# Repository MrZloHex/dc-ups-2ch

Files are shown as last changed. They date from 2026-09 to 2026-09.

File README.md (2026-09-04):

# DC-UPS-2CH — ESP32 backup power controller for network gear

> Two-channel DC UPS for a Wi-Fi router + ONT / optical terminal, built around
> an off-the-shelf 24 V AC/DC brick, an XL4016 charger, an AGM battery and two
> XL6009 buck-boost outputs. An ESP32 supervises the whole thing, exposes a
> local web panel, sends notifications through `ntfy.sh`, and even answers
> read-only status commands back through the same ntfy topic.

**Firmware version:** `2026.09.02-v6` · **Hardware:** `v2.1` · **License:** [GPL-3.0-or-later](LICENSE)
· **[Documentation site](https://mrzlohex.github.io/dc-ups-2ch/)**
· Passport [RU](docs/DC_UPS_documentation_v6.tex) / [EN](docs/DC_UPS_documentation_v6_en.tex)
· User manual [RU](docs/DC_UPS_user_manual_v6.tex) / [EN](docs/DC_UPS_user_manual_v6_en.tex)

<p align="center">
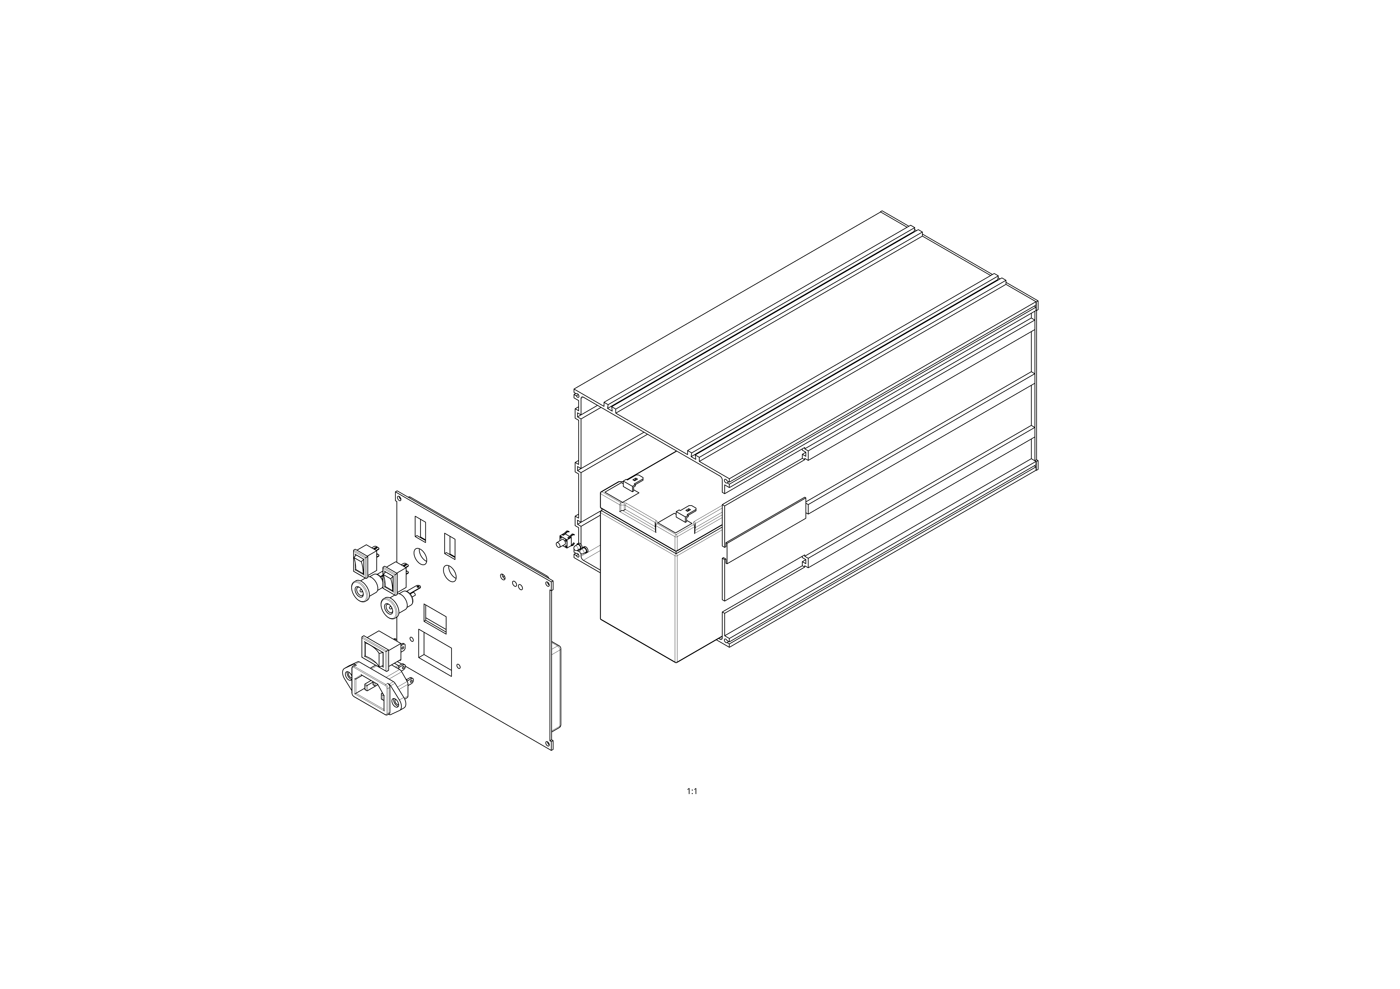
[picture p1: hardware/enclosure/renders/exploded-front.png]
Exploded isometric — front panel, battery, aluminium extrusion shell
  
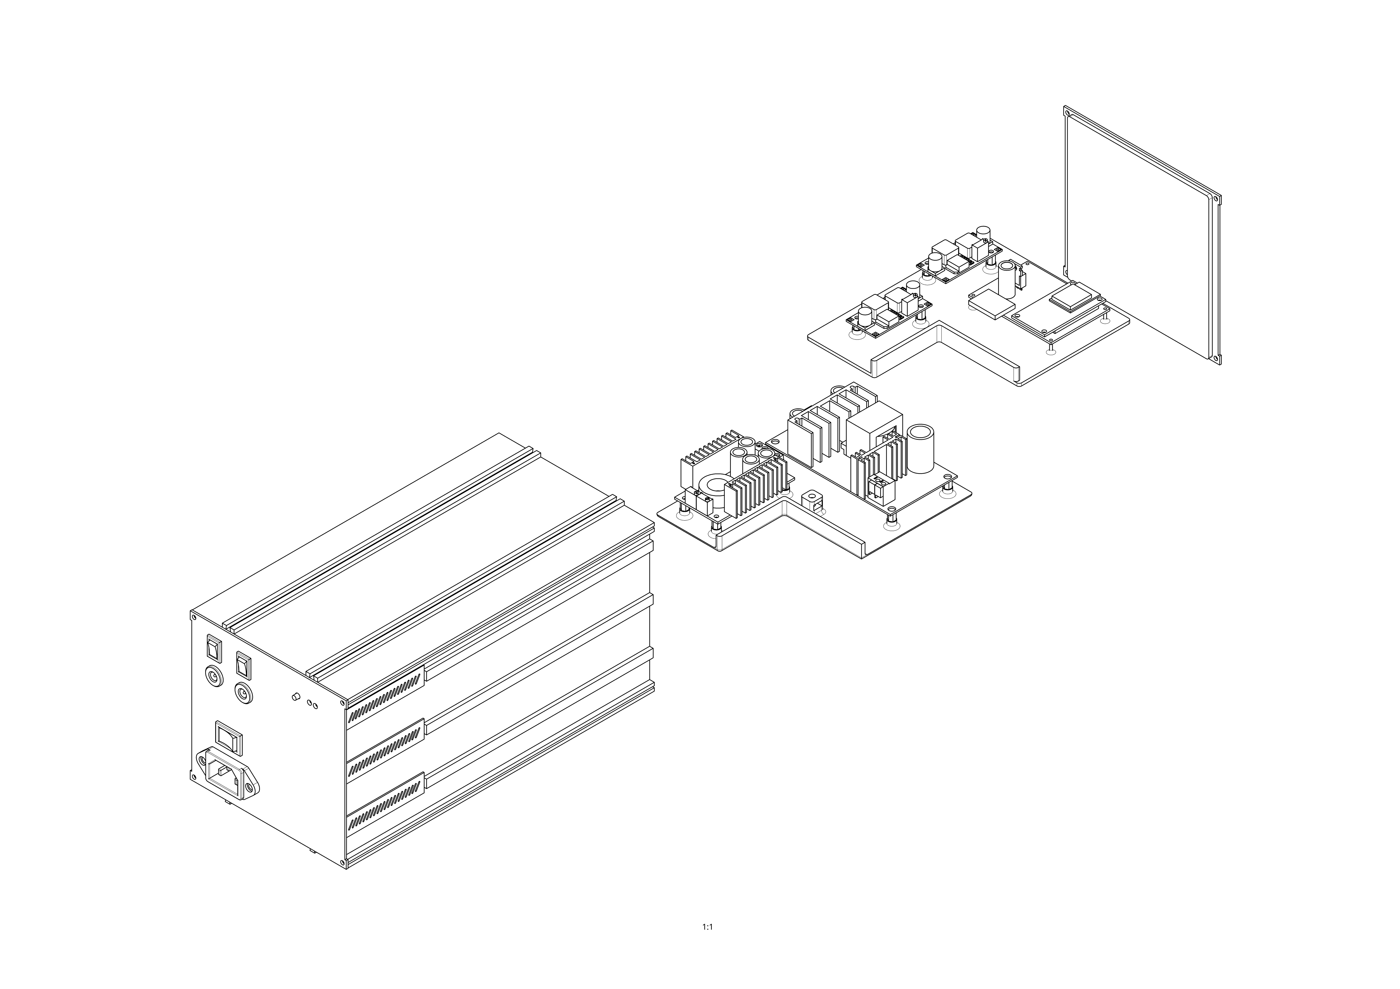
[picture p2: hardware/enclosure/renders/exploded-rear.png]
Exploded isometric — rear panel with two-tier PCB stack (XL4016 charger + 2× XL6009 boosters + ESP32)
  
</p>

<p align="center"><sub>
  Exploded isometric views from the public
  <a href="https://cad.onshape.com/documents/ea66c330322b844216a03713/w/1c92cc427e11be4cf82566dd/e/3ae3fbe0cc714edd3fc95852">Onshape</a>
  model. Left: front panel with IEC C14 inlet and two DC output sockets pulled off, AGM battery visible in the aluminium extrusion. Right: back panel and the two-tier power PCB assembly pulled off.
  STEP files: <a href="hardware/enclosure/step/">hardware/enclosure/step/</a>.
</sub></p>

---

## Why this exists

This project keeps the hardware boring (all modules you can buy on any
marketplace) and puts the intelligence in the ESP32 firmware:

- automatic mains ↔ battery switching (via the shared 13.8 V bus, no relay);
- true low-voltage disconnect with configurable thresholds and hysteresis;
- **two independent DC outputs** (ROUTER, ONT) with per-channel manual override
  and remote restart;
- automatic Wi-Fi / internet health check with staged recovery (probe →
  restart the failing layer: ONT if only WAN is dead, ROUTER if Wi-Fi itself
  is gone → restart both → optionally reboot the ESP);
- push notifications via [ntfy.sh](https://ntfy.sh/) — outages, LVD, boots,
  auto-recovery actions;
- inbound read-only commands over ntfy: `!ups`, `!ups status`, `!ups ping`;
- self-hosted web panel with mDNS (`http://dc-ups.local/`);
- captive-portal setup AP (`DC-UPS-Setup`) when Wi-Fi isn't configured or dies;
- two deep-sleep modes: emergency (timer wake, keeps checking mains) and
  shelf-sleep (button wake only, for storage/transport).

## Hardware overview

```
230 V AC ─▶ AC/DC 24 V ─▶ XL4016 CC/CV ─▶ 13.8 V bus ◀─▶ AGM 12 V 7 Ah
                                              │
                          ┌───────────────────┼───────────────────┐
                          ▼                                       ▼
                  P-MOSFET + XL6009                       P-MOSFET + XL6009
                          │                                       │
                          ▼                                       ▼
                        ROUTER                                  ONT / AUX
                          ▲                                       ▲
                          │                                       │
                          └─── GPIO32 ─── ESP32 ─── GPIO25 ───────┘
                                            │
                                            ▼
                                    ADC ◀── 24 V bus & battery
                                            │
                                    Button ─┘ (GPIO14, EXT0 wake)
```

Full wiring, GPIO map, calibration and BOM: [`hardware/README.md`](hardware/README.md).

## Getting started

### Prerequisites

- ESP32 DevKit v1 (ESP-WROOM-32, USB-C or micro, CH340/CP2102 — either is fine)
- [PlatformIO Core](https://platformio.org/install/cli) (or the VS Code extension)
- The rest of the hardware from [`hardware/README.md`](hardware/README.md)

### Build & flash

```bash
git clone https://github.com/MrZloHex/dc-ups-2ch.git
cd dc-ups-2ch

# Everything at once (firmware + PDFs), stamped with version + git hash + date:
make                   # or: make all
make upload            # firmware + flash
make monitor           # 115200 baud

# Or use PlatformIO directly — the pre-script still stamps the build:
pio run
pio run -t upload
pio device monitor
```

The version stamped into the firmware and both PDFs comes from the top-level
`VERSION` file plus `git rev-parse --short HEAD` and today's UTC date. It
shows up in the serial boot log, in the web panel header, in ntfy status
replies, and on the printable device label. Override any of them:

```bash
make VERSION=2026.10.01-v7            # bump semantic version for a release build
make DOCREV="Rev. 3"                  # override the document revision label
```

`make version` prints exactly what will be stamped, `make help` lists every
target.

### First boot

1. On first boot (or if the saved Wi-Fi credentials fail) the device spins up
   an open access point named **`DC-UPS-Setup`** with password
   `dc-ups-setup`.
2. Connect any phone/laptop, browse to `http://192.168.4.1/`, fill in your
   Wi-Fi SSID/password, your `ntfy.sh` topic (**pick a long, unguessable
   string** — the topic is effectively a secret URL), and hit save. The device
   reboots.
3. From now on the panel lives at `http://dc-ups.local/` (mDNS) or the IP the
   ESP32 pushes to your ntfy topic on every successful connect.

### Button reference

| Gesture | Action |
|---|---|
| 1× short press | send full status message to ntfy (2× green blink = ok) |
| 2× short press | open setup AP for 15 minutes (both LEDs blink once) |
| Hold 10 s | Shelf Sleep — everything off, wake only by another press |
| Any press in shelf | boot the device again |

### ntfy commands

Send any of these to your topic (e.g. from the ntfy app or `curl`):

```
!ups          # or "!ups status" — reply with full status
!ups ping     # reply "PONG ..." + full status
```

The device polls the topic ~every 15 s while online. There are **no
inbound control commands** on purpose: the topic is only a read-only status
channel.

## Documentation

- **[Documentation site](https://mrzlohex.github.io/dc-ups-2ch/)** - GitHub
  Pages landing page linking to every PDF. This URL is also encoded in the QR
  code printed on the enclosure label - scan the label with any phone to jump
  straight here.
- [`hardware/README.md`](hardware/README.md) - BOM, GPIO map, ASCII wiring, calibration
- [`hardware/enclosure/`](hardware/enclosure/) - 3D-printable case
- [`docs/DC_UPS_documentation_v6.tex`](docs/DC_UPS_documentation_v6.tex) /
  [`docs/DC_UPS_documentation_v6_en.tex`](docs/DC_UPS_documentation_v6_en.tex)
  - full passport, service manual, warranty template (Russian and English
  variants; both stamped from the same `build_info.tex`)
- [`docs/DC_UPS_user_manual_v6.tex`](docs/DC_UPS_user_manual_v6.tex) /
  [`docs/DC_UPS_user_manual_v6_en.tex`](docs/DC_UPS_user_manual_v6_en.tex)
  - short A5 user manual (Russian and English) with local-panel + docs-site QR codes
- [`docs/DC_UPS_label_v6.tex`](docs/DC_UPS_label_v6.tex) - 90 × 55 mm enclosure
  label; QR code encodes the documentation-site URL above
- [Printables](https://www.printables.com/model/1832207-dc-ups-2ch-esp32-dc-ups-for-router-ont) - Page on printables
- [MakerWorld](https://makerworld.com/en/models/3258940-dc-ups-2ch-esp32-dc-ups-for-router-ont#profileId-3694235) - Page on MakerWorld

## Contributing

Issues and PRs welcome. Please:

- keep the firmware buildable with the pinned `espressif32@^6.9.0` platform
  (the watchdog and RTC-GPIO APIs used here are frozen on that major);
- avoid new external Arduino libraries — everything so far fits in the core;
- match the module split described above rather than dumping new features
  into `main.cpp`.

## License

**Firmware & documentation:** GNU General Public License v3.0 or later —
see [LICENSE](LICENSE). If you build a product on top of this firmware,
you must make your source available under the same license.

Hardware wiring is documented for personal / educational use; recycled
AC/DC bricks and Chinese DC/DC modules used in the BOM come with their
own certifications (or don't).

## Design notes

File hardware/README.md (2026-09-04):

# DC-UPS-2CH — hardware notes

> This is a "buy the modules, don't design a PCB" project. Everything is
> wired point-to-point (or on a small perfboard) so anyone with a soldering
> iron can reproduce it. 

## Bill of materials

| # | Part | Notes |
|---|---|---|
| 1 | ESP32 DevKit v1 (ESP-WROOM-32) | USB-C or micro; CH340/CP2102 both fine |
| 2 | AC/DC brick 230 V → 24 V, ≥ 60 W | any reputable enclosed switcher |
| 3 | XL4016 CC/CV step-down module | set to **13.8 V** open-circuit, current-limit ≈ **1.5 A** |
| 4 | AGM/SLA battery 12 V, 7 Ah | any brand that fits your enclosure; keep the terminal type same  |
| 5 | 2 × XL6009 buck-boost | one per output; adjust to the actual load voltage before wiring  |
| 6 | 2 × P-MOSFET, e.g. IRF9Z34N | high-side switch; needs to handle your peak output current |
| 7 | 2 × 2N2222 NPN | gate driver from a 3.3 V GPIO to a P-MOSFET gate |
| 8 | 2 × 10 kΩ gate pull-up (Gate ↔ Source) | keeps the P-MOSFET fully off when the NPN is off |
| 9 | 2 × 100 kΩ + 2 × 10 kΩ | voltage dividers for `V_BATT` and `V_24V` sensing |
|10 | 1 × 5 A automotive fuse + holder | mount at the battery `+` terminal, as close as possible |
|11 | Reverse-blocking / OR-ing diode (optional) | if your specific arrangement needs it — depends on charger topo  |
|12 | 1 × 6 × 6 mm tact switch | GPIO14 to GND (uses internal pull-up) |
|13 | 2 × LED (green + red) + series resistors | ~330 Ω is fine for 3.3 V drive |
|14 | Screw terminals / DC barrel jacks | pick to match your router's / ONT's input plugs |

Anything not on this list (heatsinks, standoffs, wire, enclosure) is up to you.

## GPIO map

| Pin | Direction | Function |
|---|---|---|
| `GPIO35` | ADC1_IN7  | `V_BATT` sense (100 kΩ / 10 kΩ divider → x11) |
| `GPIO34` | ADC1_IN6  | `V_24V` sense (100 kΩ / 10 kΩ divider → x11) |
| `GPIO32` | OUT | `ROUTER` channel: NPN base → P-MOSFET gate |
| `GPIO25` | OUT | `ONT` channel: NPN base → P-MOSFET gate |
| `GPIO14` | IN_PULLUP | service button to GND; **RTC-GPIO → EXT0 wake source**|
| `GPIO13` | OUT | green LED: mains present |
| `GPIO12` | OUT | red LED: battery / warning / fault |

> **ADC1 only.** Voltage sensing must stay on GPIO32-39. ADC2 is unusable
> while Wi-Fi is on.

> **GPIO14 is a specific choice.** It's an RTC-GPIO on the classic ESP32,
> which is exactly what's needed to wake from Shelf Sleep via EXT0. Do not
> reassign to a non-RTC pin.

## Voltage divider math

```
V_pin = V_source · R_bottom / (R_top + R_bottom)
V_pin = V_source · 10k / (100k + 10k) = V_source / 11

At V_source = 15.0 V  ->  V_pin ≈ 1.36 V  (well inside 0..3.3 V ADC range)
At V_source = 13.8 V  ->  V_pin ≈ 1.25 V
At V_source = 24.0 V  ->  V_pin ≈ 2.18 V
```

The firmware assumes `DIV = 11.0` for both channels. If you use different
resistors, edit `DIV_VBATT` / `DIV_VGRID` in
[`include/ups_common.h`](../include/ups_common.h). Fine per-device correction
(±3 %) is done at runtime through the web panel using a multimeter — no code
change needed.

## ASCII wiring (one channel — mirror for the second)

```
              +Vbus 13.8 V (charger + battery via fuse)
                          │                  │
                          │                  │ 
                          │Source           100 KOhm  
                     ┌────┴─────┐    Gate    │ 	
                     │ P-MOSFET │ ◀──────────┤
                     │ (S=Vbus) │            │
                     └────┬─────┘            │
                          │                100 Ohm  
                     Drain│                  │
                          ▼                  │
                    XL6009 IN                │
                                             │Collector
                                             │
                                   ┌─────────┴──┐
                                   │   2N2222   │  (BJT open when GPIO HIGH)
           GPIO32 ── 1kOhm ──┬───▶ │            │
        (or  GPIO25)      10 KOhm  └────────────┘
                             │
                            GND
```

## Charger settings (XL4016)

1. Disconnect everything downstream.
2. Feed the XL4016 from the 24 V brick.
3. **Voltage pot:** turn the CV trim until the open-circuit output at the
   pads that will feed the battery reads exactly **13.8 V** at the battery
   terminals. Compensate for wire drop by measuring at the battery, not at
   the module.
4. **Current pot:** short the output through an ammeter for a brief pulse
   (or use a resistive dummy load) and set the CC limit to **≈ 1.5 A**.
5. Only then connect the battery.

## Setting the XL6009 outputs

1. Look up the required voltage of the load (router: usually 12 V, ONT:
   often 12 V, sometimes 9 V). Verify with a multimeter on the *original*
   PSU under no load.
2. Feed each XL6009 from the 13.8 V bus (through a temporary lead — do
   **not** connect the load yet).
3. Turn the output pot until the measured voltage matches the target
   within ±0.2 V.
4. Only then connect the load through the DC barrel jack.

## Calibration

The web panel has two calibration fields (`Cal battery` / `Cal 24 V`).
Procedure:

1. Measure the real battery voltage with a multimeter directly at the
   battery terminals.
2. Type the exact reading into the *battery* calibration field and press
   the corresponding button. The firmware computes a per-device
   correction factor and saves it in NVS.
3. Repeat for the 24 V line, measured directly at the AC/DC brick output.

The correction factors are stored as `calVbatt` / `calVgrid` floats
(default 1.000) in NVS and are picked up on the next reading.

## Safety 

- **230 V AC is present inside the enclosure.** Before opening: unplug
  mains, disconnect the battery fuse.
- The AGM battery is a *short-circuit hazard* — hundreds of amps into a
  screwdriver dropped across the terminals. Always disconnect the fuse
  first when working near it.
- Never bypass the fuse. Its job is to isolate a dead-short before the
  battery cables catch fire.
- Do not skip the initial no-load setup of the XL6009 outputs — a wrong
  voltage will kill a router.
- The AGM battery is a consumable. Replace when the measured autonomy
  drops noticeably, the case bulges, or the terminals show corrosion.

## Suggested layout

Keep the AC/DC brick, the XL4016 and the battery physically separated
from the ESP32 and the two XL6009 outputs, or at least route wiring so
that the switching noise from the buck-boost modules doesn't couple into
the ADC dividers. A short common ground point (star ground) near the
battery negative helps a lot.

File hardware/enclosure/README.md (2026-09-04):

# DC-UPS-2CH — enclosure

3D-printable enclosure for the DC-UPS-2CH controller. Modelled in
[Onshape](https://cad.onshape.com/documents/ea66c330322b844216a03713/w/1c92cc427e11be4cf82566dd/e/3ae3fbe0cc714edd3fc95852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)

<p align="center">
  Exploded isometric — front panel, battery, aluminium extrusion shell
  Exploded isometric — rear panel with PCB stack
</p>

## Contents

```
hardware/enclosure/
├── README.md              this file
├── renders/
│   ├── exploded-front.png     iso view: front panel + battery exploded
│   └── exploded-rear.png      iso view: back panel + PCB stack exploded
├── step/                  neutral STEP exports (for CAD / re-modelling)
│   ├── Main.step              main aluminium-extrusion body
│   ├── Level 1.step           lower PCB tier (charger + XL6009 outputs)
│   ├── Level 2.step           upper PCB tier (ESP32 + I/O)
│   ├── Side 1.step            front panel (IEC C14 inlet + DC output sockets)
│   ├── Side 2.step            rear panel (button + LEDs + cable exits)
│   ├── Battery Holder.step    AGM 12 V / 7 Ah cradle
│   └── Dummy Sky.step         placeholder for the top cover volume
└── 3mf/                   slicer-ready assemblies (drop straight into a slicer)
    ├── DC_UPS.3mf             full assembly view
    ├── Main.3mf, Level 1.3mf, Level 2.3mf, Side 1.3mf, Side 2.3mf,
    └── Battery Holder.3mf, Dummy Sky.3mf
```

## Print settings (baseline)

| Setting | Value |
|---|---|
| Material | PETG (preferred) or ABS/ASA — this thing sits next to a  |
| | charger that gets warm. **Not PLA** for the case body. |
| Nozzle | 0.4 mm |
| Layer height | 0.20 mm |
| Walls | 4 perimeters (strength around threaded inserts) |
| Top/bottom | 5 layers each |
| Infill | 25–30 % gyroid |
| Supports | Only for lid cutouts if needed — orient case bottom |
| | opening-up so the battery bay prints support-free |
| Brim | 5 mm on the case bottom, none on the lid |

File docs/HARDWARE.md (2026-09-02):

# DC-UPS-2CH — hardware notes

> This is a "buy the modules, don't design a PCB" project. Everything is
> wired point-to-point (or on a small perfboard) so anyone with a soldering
> iron can reproduce it. The full Russian passport (`DC_UPS_documentation_v6.tex`)
> has the same information plus service checklists, warranty template and
> service diagrams — this file is the English quick reference.

## Bill of materials

| # | Part | Notes |
|---|---|---|
| 1 | ESP32 DevKit v1 (ESP-WROOM-32) | USB-C or micro; CH340/CP2102 both fine |
| 2 | AC/DC brick 230 V → 24 V, ≥ 60 W | any reputable enclosed switcher |
| 3 | XL4016 CC/CV step-down module | set to **13.8 V** open-circuit, current-limit ≈ **1.5 A** |
| 4 | AGM/SLA battery 12 V, 7 Ah | any brand that fits your enclosure; keep the terminal type same  |
| 5 | 2 × XL6009 buck-boost | one per output; adjust to the actual load voltage before wiring  |
| 6 | 2 × P-MOSFET, e.g. IRF9Z34N | high-side switch; needs to handle your peak output current |
| 7 | 2 × 2N2222 NPN | gate driver from a 3.3 V GPIO to a P-MOSFET gate |
| 8 | 2 × 10 kΩ gate pull-up (Gate ↔ Source) | keeps the P-MOSFET fully off when the NPN is off |
| 9 | 2 × 100 kΩ + 2 × 10 kΩ | voltage dividers for `V_BATT` and `V_24V` sensing |
|10 | 1 × 5 A automotive fuse + holder | mount at the battery `+` terminal, as close as possible |
|11 | Reverse-blocking / OR-ing diode (optional) | if your specific arrangement needs it — depends on charger topo  |
|12 | 1 × 6 × 6 mm tact switch | GPIO14 to GND (uses internal pull-up) |
|13 | 2 × LED (green + red) + series resistors | ~330 Ω is fine for 3.3 V drive |
|14 | Screw terminals / DC barrel jacks | pick to match your router's / ONT's input plugs |

Anything not on this list (heatsinks, standoffs, wire, enclosure) is up to you.

## GPIO map

| Pin | Direction | Function |
|---|---|---|
| `GPIO35` | ADC1_IN7  | `V_BATT` sense (100 kΩ / 10 kΩ divider → x11) |
| `GPIO34` | ADC1_IN6  | `V_24V` sense (100 kΩ / 10 kΩ divider → x11) |
| `GPIO32` | OUT | `ROUTER` channel: NPN base → P-MOSFET gate |
| `GPIO25` | OUT | `ONT` channel: NPN base → P-MOSFET gate |
| `GPIO14` | IN_PULLUP | service button to GND; **RTC-GPIO → EXT0 wake source**|
| `GPIO13` | OUT | green LED: mains present |
| `GPIO12` | OUT | red LED: battery / warning / fault |

> **ADC1 only.** Voltage sensing must stay on GPIO32-39. ADC2 is unusable
> while Wi-Fi is on.

> **GPIO14 is a specific choice.** It's an RTC-GPIO on the classic ESP32,
> which is exactly what's needed to wake from Shelf Sleep via EXT0. Do not
> reassign to a non-RTC pin.

## Voltage divider math

```
V_pin = V_source · R_bottom / (R_top + R_bottom)
V_pin = V_source · 10k / (100k + 10k) = V_source / 11

At V_source = 15.0 V  ->  V_pin ≈ 1.36 V  (well inside 0..3.3 V ADC range)
At V_source = 13.8 V  ->  V_pin ≈ 1.25 V
At V_source = 24.0 V  ->  V_pin ≈ 2.18 V
```

The firmware assumes `DIV = 11.0` for both channels. If you use different
resistors, edit `DIV_VBATT` / `DIV_VGRID` in
[`include/ups_common.h`](../include/ups_common.h). Fine per-device correction
(±3 %) is done at runtime through the web panel using a multimeter — no code
change needed.

## ASCII wiring (one channel — mirror for the second)

```
              +Vbus 13.8 V (charger + battery via fuse)
                          │
                          │
                     ┌────┴─────┐    Gate 10 kΩ pull-up
                     │  P-MOSFET │ ◀──────────┐
                     │  (S=Vbus) │            │
                     └────┬─────┘             │
                          │                   │
                     Drain│                   │
                          ▼                   │
                    XL6009 IN                 │
                          │                   │
                    XL6009 OUT ─▶ ROUTER / ONT│
                                              │
                                              │
                                   ┌──────────┴──┐
                                   │   2N2222     │  (BJT open when GPIO HIGH)
                                   │  base ← 1kΩ │
                                   │              │
                          GPIO32 ─▶│ base         │
                    (or  GPIO25)   │ collector ──►│ P-MOSFET Gate
                                   │ emitter ─── GND
                                   └──────────────┘
```

Logic:

- GPIO **HIGH** → NPN saturates → pulls the P-MOSFET gate to GND
  → **P-MOSFET conducts → load ON**.
- GPIO **LOW** → NPN off → gate is held at Vbus by the 10 kΩ pull-up
  → **P-MOSFET off → load OFF**.

## Charger settings (XL4016)

1. Disconnect everything downstream.
2. Feed the XL4016 from the 24 V brick.
3. **Voltage pot:** turn the CV trim until the open-circuit output at the
   pads that will feed the battery reads exactly **13.8 V** at the battery
   terminals. Compensate for wire drop by measuring at the battery, not at
   the module.
4. **Current pot:** short the output through an ammeter for a brief pulse
   (or use a resistive dummy load) and set the CC limit to **≈ 1.5 A**.
5. Only then connect the battery.

## Setting the XL6009 outputs

1. Look up the required voltage of the load (router: usually 12 V, ONT:
   often 12 V, sometimes 9 V). Verify with a multimeter on the *original*
   PSU under no load.
2. Feed each XL6009 from the 13.8 V bus (through a temporary lead — do
   **not** connect the load yet).
3. Turn the output pot until the measured voltage matches the target
   within ±0.2 V.
4. Only then connect the load through the DC barrel jack.

## Calibration

The web panel has two calibration fields (`Cal battery` / `Cal 24 V`).
Procedure:

1. Measure the real battery voltage with a multimeter directly at the
   battery terminals.
2. Type the exact reading into the *battery* calibration field and press
   the corresponding button. The firmware computes a per-device
   correction factor and saves it in NVS.
3. Repeat for the 24 V line, measured directly at the AC/DC brick output.

The correction factors are stored as `calVbatt` / `calVgrid` floats
(default 1.000) in NVS and are picked up on the next reading.

## Safety 

- **230 V AC is present inside the enclosure.** Before opening: unplug
  mains, disconnect the battery fuse.
- The AGM battery is a *short-circuit hazard* — hundreds of amps into a
  screwdriver dropped across the terminals. Always disconnect the fuse
  first when working near it.
- Never bypass the fuse. Its job is to isolate a dead-short before the
  battery cables catch fire.
- Do not skip the initial no-load setup of the XL6009 outputs — a wrong
  voltage will kill a router.
- The AGM battery is a consumable. Replace when the measured autonomy
  drops noticeably, the case bulges, or the terminals show corrosion.

## Suggested layout

Keep the AC/DC brick, the XL4016 and the battery physically separated
from the ESP32 and the two XL6009 outputs, or at least route wiring so
that the switching noise from the buck-boost modules doesn't couple into
the ADC dividers. A short common ground point (star ground) near the
battery negative helps a lot.

## Enclosure

A 3D-printable enclosure lives at
[`../hardware/enclosure/`](../hardware/enclosure/). Modelled in
Onshape, distributed as STEP files (import directly in PrusaSlicer /
Bambu Studio / OrcaSlicer), licensed under CC-BY-SA 4.0. Ready-to-paste
listings for Printables and MakerWorld are in the same folder.

Recommended print: **PETG** (or ABS/ASA) — not PLA, because the
charger and both DC/DC modules run warm enough to creep PLA over time.
0.20 mm layers, 4 perimeters, 25–30 % gyroid infill, supports only for
lid cutouts.

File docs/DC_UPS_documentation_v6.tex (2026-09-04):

\documentclass[11pt,a4paper]{article}

\usepackage{fontspec}
\setmainfont{DejaVu Serif}
\setsansfont{DejaVu Sans}
\setmonofont{DejaVu Sans Mono}
\usepackage[russian]{babel}
\usepackage{geometry}
\geometry{left=20mm,right=20mm,top=18mm,bottom=20mm}
\usepackage{microtype}
\usepackage{array,tabularx,longtable,booktabs,multirow}
\usepackage{enumitem}
\usepackage{graphicx}
% Renders exported from the Onshape model live next to the STEP files.
\graphicspath{{../hardware/enclosure/renders/}}
\usepackage{xcolor}
\usepackage{hyperref}
\usepackage{fancyhdr}
\usepackage{titlesec}
\usepackage{lastpage}
\usepackage{tcolorbox}
\usepackage{caption}
\usepackage{float}
\usepackage{qrcode}
\usepackage{tikz}
\usetikzlibrary{positioning}

% Build identity is normally injected by `make -C docs build_info`.
% Fallbacks below let the .tex compile standalone in a TeX editor without make.
\IfFileExists{build_info.tex}{\input{build_info}}{%
  \newcommand{\hwversion}{v2.1}%
  \newcommand{\fwversion}{dev}%
  \newcommand{\builddate}{unknown}%
  \newcommand{\buildcommit}{unknown}%
  \newcommand{\docrev}{unknown}%
}

\hypersetup{colorlinks=true,linkcolor=black,urlcolor=blue,pdfauthor={Изготовитель DC-UPS-2CH},pdftitle={Паспорт и руководство по эксплуатации DC-UPS-2CH \fwversion}}
\setlength{\parindent}{0pt}
\setlength{\parskip}{0.45em}
\renewcommand{\arraystretch}{1.2}

\definecolor{accent}{HTML}{1E5B4F}
\definecolor{lightaccent}{HTML}{EAF3F1}
\definecolor{warn}{HTML}{8B1E1E}
\definecolor{lightwarn}{HTML}{F9ECEC}

\titleformat{\section}{\Large\bfseries\color{accent}}{\thesection.}{0.5em}{}
\titleformat{\subsection}{\large\bfseries}{\thesubsection.}{0.5em}{}
\titleformat{\subsubsection}{\normalsize\bfseries}{\thesubsubsection.}{0.5em}{}

\pagestyle{fancy}
\fancyhf{}
\lhead{DC-UPS-2CH}
\rhead{Паспорт и руководство}
\cfoot{Стр. \thepage}
\renewcommand{\headrulewidth}{0.4pt}
\setlength{\headheight}{14pt}

\newcommand{\fieldline}[1]{\textbf{#1}: \rule{0.55\linewidth}{0.4pt}}
\newcommand{\blankfig}[2]{%
  \begin{figure}[H]\centering
  \fbox{\parbox[c][#1][c]{0.90\textwidth}{\centering\sffamily\color{gray}\Large #2\\[0.5em]\normalsize Вставить скриншот / изображение}}
  \end{figure}
}
% \realfig{filename}{caption} — inserts an image full text-width with a caption line.
\newcommand{\realfig}[2]{%
  \begin{figure}[H]\centering
  \\[0.4em]
  {\sffamily\small #2}
  \end{figure}
}
\newcommand{\yesno}{□ да\quad □ нет}

\begin{document}

% -------------------- TITLE --------------------
\begin{titlepage}
\centering
\vspace*{18mm}
{\sffamily\bfseries\fontsize{28}{34}\selectfont DC-UPS-2CH\\[3mm]}
{\sffamily\Large Источник резервного питания сетевого оборудования\\[12mm]}

\begin{tcolorbox}[width=0.85\textwidth,colback=lightaccent,colframe=accent,boxrule=0.8pt,arc=2mm]
\centering
{\Large\bfseries ПАСПОРТ ИЗДЕЛИЯ\\
РУКОВОДСТВО ПО ЭКСПЛУАТАЦИИ\\
СЕРВИСНАЯ ИНСТРУКЦИЯ\\
ГАРАНТИЙНЫЙ ТАЛОН}
\end{tcolorbox}

\vfill
\begin{tabular}{@{}p{55mm}p{90mm}@{}}
Модель изделия: & DC-UPS-2CH \hwversion \\
Версия прошивки: & \fwversion \\
Редакция документа: & \builddate\ / \docrev \\
Серийный номер: & \rule{70mm}{0.4pt} \\
Дата изготовления: & \rule{70mm}{0.4pt} \\
Изготовитель / сборщик: & \rule{70mm}{0.4pt} \\
Контакт: & \rule{70mm}{0.4pt} \\
\end{tabular}

\vfill
{\small Документ предназначен для владельца изделия и для выполнения регламентного обслуживания.\\
Хранить вместе с устройством. Актуализировано для прошивки \fwversion\ (сборка \buildcommit, \builddate).}
\end{titlepage}

\tableofcontents
\newpage

% -------------------- 1 --------------------
\section{Общие сведения}

\subsection{Назначение}
DC-UPS-2CH представляет собой двухканальный источник резервного питания постоянного тока для сетевого и слаботочного оборудования. Устройство предназначено для поддержания работы Wi-Fi роутера, ONT/оптического терминала, модема или другой совместимой нагрузки при пропадании сетевого питания 230~В.

Устройство сочетает сетевой источник 24~В, зарядный преобразователь, герметичный аккумулятор 12~В, два независимых выходных DC/DC-канала и управляющий контроллер ESP32. Контроллер отслеживает состояние сети и аккумулятора, управляет двумя выходами, ведёт журнал событий, выполняет автоматическое восстановление связи и предоставляет веб-интерфейс.

\subsection{Основные функции}
\begin{itemize}[leftmargin=7mm]
  \item автоматическая работа от сети и переход на аккумулятор без ручного переключения;
  \item поддерживающий заряд аккумулятора с ограничением тока;
  \item два независимых управляемых выходных канала ROUTER и ONT;
  \item защита аккумулятора от глубокого разряда (LVD);
  \item аварийный deep sleep контроллера после отключения нагрузки;
  \item периодическая проверка возврата сети во время аварийного deep sleep;
  \item отдельный режим хранения (Shelf Sleep): оба выхода и Wi-Fi выключены, пробуждение только физической кнопкой;
  \item контроль наличия Wi-Fi и доступности интернета;
  \item автоматический power-cycle выходных каналов при неисправности связи;
  \item локальный веб-интерфейс;
  \item mDNS-адрес \texttt{http://dc-ups.local/};
  \item сервисная точка доступа \texttt{DC-UPS-Setup};
  \item уведомления через сервис ntfy;
  \item read-only команды через тот же ntfy topic: \texttt{!ups}, \texttt{!ups status}, \texttt{!ups ping};
  \item журнал событий (кольцевой буфер в ОЗУ + сохранение последних записей в NVS для переживания перезагрузок);
  \item локальная тактовая кнопка: статус, setup AP и режим хранения;
  \item световая индикация состояния сети и аккумулятора.
\end{itemize}

\begin{tcolorbox}[colback=lightwarn,colframe=warn,title=Важно]
Внутри устройства присутствует опасное сетевое напряжение 230~В. Разборка, регулировка и замена внутренних компонентов выполняются только после отключения сетевого питания и аккумулятора.
\end{tcolorbox}

% -------------------- 2 --------------------
\section{Технические характеристики}

\subsection{Основные параметры}
\begin{longtable}{@{}p{70mm}p{80mm}@{}}
\toprule
\textbf{Параметр} & \textbf{Значение} \\
\midrule
\endhead
Тип изделия & Двухканальный DC-UPS для слаботочного оборудования \\
Сетевое питание & 230~В AC, 50~Гц \\
Промежуточная шина & 24~В DC от внутреннего AC/DC-модуля \\
Номинал аккумулятора & 12~В, 7~А\,ч, герметичный AGM/SLA \\
Установленная модель АКБ & \rule{60mm}{0.4pt} \\
Напряжение поддерживающего заряда & 13,8~В на клеммах АКБ (настроечное значение) \\
Ограничение тока зарядного канала & 1,5~А \\
Зарядный DC/DC-модуль & XL4016 CC/CV или установленный эквивалент \\
Количество выходов & 2 независимых канала \\
Выходные DC/DC-модули & 2\,$\times$\,XL6009 buck-boost или установленный эквивалент \\
Управляющий контроллер & ESP32 \\
Версия прошивки на момент выпуска документа & \fwversion \\
Контроль АКБ & ADC, GPIO35, делитель 100~кОм / 10~кОм \\
Контроль 24~В & ADC, GPIO34, делитель 100~кОм / 10~кОм \\
Канал ROUTER & GPIO32 $\rightarrow$ NPN 2N2222 $\rightarrow$ P-MOSFET \\
Канал ONT & GPIO25 $\rightarrow$ NPN 2N2222 $\rightarrow$ P-MOSFET \\
Сервисная кнопка & GPIO14, замыкание на GND, INPUT\_PULLUP; RTC GPIO / EXT0 wake в режиме хранения \\
LED сети & GPIO13 \\
LED АКБ/аварии & GPIO12 \\
Подтяжка затвора P-MOSFET & 10~кОм Gate--Source (по текущей схеме) \\
Модель P-MOSFET & IRF9Zxx / фактически установленный: \rule{35mm}{0.4pt} \\
Предохранитель АКБ & рекомендуемый 5~А, установить непосредственно у плюсовой клеммы \\
\bottomrule
\end{longtable}

\subsection{Параметры выходов конкретного экземпляра}
\begin{tabularx}{\textwidth}{@{}lXccc@{}}
\toprule
\textbf{Канал} & \textbf{Назначение / подключённое устройство} & \textbf{U, В} & \textbf{I nom, А} & \textbf{I max, А} \\
\midrule
ROUTER & \rule{45mm}{0.4pt} & \rule{12mm}{0.4pt} & \rule{12mm}{0.4pt} & \rule{12mm}{0.4pt} \\
ONT & \rule{45mm}{0.4pt} & \rule{12mm}{0.4pt} & \rule{12mm}{0.4pt} & \rule{12mm}{0.4pt} \\
\bottomrule
\end{tabularx}

\begin{tcolorbox}[colback=lightaccent,colframe=accent,title=Примечание по выходным токам]
Максимальный допустимый ток каждого выхода определяется фактически установленным DC/DC-модулем, охлаждением, проводкой, разъёмом и P-MOSFET. Перед передачей изделия владельцу значения должны быть установлены по результатам нагрузочного испытания и вписаны в таблицу и на шильдик. Не следует указывать номинал только по рекламному ``максимальному току'' модуля XL6009.
\end{tcolorbox}

\subsection{Пороговые значения защиты}
\begin{tabularx}{\textwidth}{@{}XlX@{}}
\toprule
\textbf{Функция} & \textbf{Значение по умолчанию} & \textbf{Назначение} \\
\midrule
Предупреждение АКБ & 11,5~В & Уведомление о приближении разряда \\
LVD / отключение нагрузки & 11,0~В & Отключение ROUTER и ONT при отсутствии сети \\
Восстановление после LVD & 12,5~В & Разрешение повторного включения после восстановления АКБ \\
Дополнительный аварийный порог & 10,8~В & Второй уровень контроля низкого напряжения \\
Задержка перед deep sleep & 30~с & Даёт время завершить уведомление и стабилизировать состояние \\
Период пробуждения в аварийном deep sleep & 30~с & Проверка возврата 24~В и состояния АКБ \\
Shelf Sleep / режим хранения & без периодического таймера & Пробуждение только кнопкой GPIO14 (EXT0) \\
``Сеть есть'' & выше 15,0~В на контролируемой 24-В линии & Верхний порог гистерезиса \\
``Сети нет'' & ниже 10,0~В на контролируемой 24-В линии & Нижний порог гистерезиса \\
Антидребезг сети & 3~с & Исключение ложных переключений \\
\bottomrule
\end{tabularx}

Все перечисленные пороги, кроме аппаратных номиналов, могут быть изменены в веб-интерфейсе. Значения в данном документе соответствуют настройкам прошивки по умолчанию.

% -------------------- 3 --------------------
\section{Структура и принцип действия}

\subsection{Упрощённая структурная схема}
\begin{center}
\begin{tikzpicture}[scale=0.78,transform shape,>=latex, node distance=7mm and 7mm, every node/.style={font=\sffamily\small}]
\node[draw,rounded corners,minimum width=28mm,minimum height=10mm] (ac) {230 В AC};
\node[draw,rounded corners,right=of ac,minimum width=32mm,minimum height=10mm] (psu) {AC/DC 24 В};
\node[draw,rounded corners,right=of psu,minimum width=34mm,minimum height=10mm] (chg) {XL4016 CC/CV};
\node[draw,rounded corners,right=of chg,minimum width=30mm,minimum height=10mm] (bus) {13,8 В / АКБ};
\node[draw,rounded corners,below=12mm of bus,minimum width=30mm,minimum height=10mm] (bat) {AGM 12 В 7 А·ч};
\node[draw,rounded corners,below left=18mm and 15mm of bus,minimum width=36mm,minimum height=10mm] (r) {P-MOSF 1 + XL6009};
\node[draw,rounded corners,below right=18mm and 15mm of bus,minimum width=36mm,minimum height=10mm] (o) {P-MOSF 2 + XL6009};
\node[draw,rounded corners,below=13mm of r,minimum width=28mm,minimum height=9mm] (rr) {ROUTER};
\node[draw,rounded corners,below=13mm of o,minimum width=28mm,minimum height=9mm] (oo) {ONT / AUX};
\node[draw,rounded corners,below=35mm of bus,minimum width=34mm,minimum height=10mm,fill=lightaccent] (esp) {ESP32};
\draw[->] (ac)--(psu); \draw[->] (psu)--(chg); \draw[->] (chg)--(bus); \draw[<->] (bus)--(bat);
\draw[->] (bus)--(r); \draw[->] (bus)--(o); \draw[->] (r)--(rr); \draw[->] (o)--(oo);
\draw[->,dashed] (esp)--node[left]{GPIO32}(r); \draw[->,dashed] (esp)--node[right]{GPIO25}(o);
\draw[->,dashed] (bus)--node[right]{ADC}(esp);
\end{tikzpicture}
\end{center}

\subsection{Штатный режим}
При наличии сетевого питания внутренний AC/DC-модуль формирует 24~В. Зарядный модуль XL4016 понижает напряжение и поддерживает на аккумуляторной шине установленное напряжение 13,8~В с ограничением суммарного тока до 1,5~А. Нагрузка и заряд аккумулятора питаются от общей шины после развязывающего диода согласно фактической сборке.

\subsection{Работа от аккумулятора}
После пропадания 24-В линии аккумулятор автоматически становится источником питания общей шины. Отдельного реле переключения не требуется. Контроллер фиксирует пропадание сети, оставляет разрешённые каналы включёнными и отправляет уведомление при наличии связи.

\subsection{Защита от глубокого разряда}
При работе без сети контроллер сравнивает напряжение АКБ с установленными порогами. При достижении LVD оба выхода отключаются. Повторное включение после срабатывания LVD не разрешается до достижения порога восстановления либо возврата сети.

После LVD и снятия нагрузки контроллер через установленную задержку переходит в \textbf{аварийный deep sleep}, не ожидая повторного падения напряжения после естественного ``отскока'' разгруженного аккумулятора. В этом режиме ESP32 периодически просыпается по таймеру только для измерения АКБ и 24-В линии. Полный запуск выполняется при возврате сети либо при восстановлении АКБ до порога разрешённого запуска.

\subsection{Два режима сна}
\textbf{Аварийный deep sleep} запускается автоматически при низком АКБ и отсутствии сети. Оба выхода выключены, Wi-Fi выключен, контроллер просыпается через заданный интервал (по умолчанию 30~с), быстро измеряет АКБ и линию 24~В и снова засыпает, если условия восстановления не выполнены.

\textbf{Shelf Sleep / режим хранения} запускается только длительным удержанием сервисной кнопки. В этом режиме оба выхода, Wi-Fi, mDNS и setup AP выключаются, таймер пробуждения не используется. Единственный источник пробуждения --- физическая кнопка GPIO14 через EXT0. Возврат сетевого питания 230~В сам по себе \textbf{не выводит устройство из режима хранения}. Для включения необходимо нажать кнопку.

% -------------------- 4 --------------------
\section{Органы управления и индикация}

\subsection{Светодиоды}
\begin{tabularx}{\textwidth}{@{}lX@{}}
\toprule
\textbf{Индикатор} & \textbf{Назначение} \\
\midrule
Зелёный, GPIO13 & Индикация наличия внешнего питания / состояния сети \\
Красный, GPIO12 & Индикация состояния АКБ, предупреждения и аварийного режима \\
\bottomrule
\end{tabularx}

Дополнительные шаблоны:
\begin{itemize}
  \item зелёный LED мигает $\approx$2~Гц --- ESP32 запустилась и пытается подключиться к Wi-Fi;
  \item оба LED медленно поочерёдно мигают (по 500~мс) --- активен setup AP.
\end{itemize}

\subsection{Сервисная кнопка GPIO14}
Кнопка подключается между GPIO14 и GND. В обычной работе используется внутренняя подтяжка \texttt{INPUT\_PULLUP}. GPIO14 выбран также как RTC GPIO для пробуждения из режима хранения.

\begin{tabularx}{\textwidth}{@{}p{38mm}X@{}}
\toprule
\textbf{Действие} & \textbf{Функция} \\
\midrule
Одно короткое нажатие & Отправить полный текущий статус устройства в настроенный ntfy topic. После успешной отправки зелёный LED мигает 2 раза; если Wi-Fi/ntfy недоступны, красный LED мигает 3 раза. \\
Двойное нажатие & Запустить \texttt{DC-UPS-Setup} примерно на 15 минут. Подтверждение --- краткое совместное мигание обоих LED. \\
Удержание 10~с & Перевести устройство в Shelf Sleep / режим хранения. Перед выключением красный LED мигает 3 раза; затем ROUTER и ONT выключаются, Wi-Fi отключается и ESP32 засыпает без таймера. \\
Нажатие в режиме хранения & Пробудить устройство. После пробуждения удерживаемое нажатие игнорируется до отпускания кнопки, затем выполняется штатный запуск. \\
\bottomrule
\end{tabularx}

\begin{tcolorbox}[colback=lightwarn,colframe=warn,title=Важно: режим хранения]
В Shelf Sleep устройство \textbf{не просыпается от появления 230~В}. Оно намеренно остаётся выключенным до физического нажатия кнопки. Это режим длительного хранения / перевозки, а не аварийный режим разряда АКБ.
\end{tcolorbox}

\subsection{Ручные выключатели выходов}
Если на корпусе установлены отдельные механические выключатели ROUTER и ONT, они считаются локальными аппаратными выключателями соответствующего выхода. Их положение имеет приоритет на уровне физического разрыва цепи: программное включение не восстановит питание при разомкнутом механическом выключателе.

% -------------------- 5 --------------------
\section{Веб-интерфейс и сетевые функции}

\subsection{Доступ}
При штатном подключении к локальной сети панель доступна по адресу:
\begin{center}
\texttt{http://dc-ups.local/}
\end{center}
Также панель доступна по IP-адресу, назначенному роутером. При каждом успешном подключении ESP32 к Wi-Fi прошивка может отправлять актуальный IP через ntfy.

\subsection{Сервисная точка доступа}
SSID по умолчанию: \texttt{DC-UPS-Setup}.\\
Пароль по умолчанию: \texttt{dc-ups-setup}.\\
Параметры могут быть изменены владельцем через веб-интерфейс.

\begin{tcolorbox}[colback=lightaccent,colframe=accent,title=Рекомендация]
Пароль setup AP и пароль администратора веб-панели не следует печатать на наружной наклейке устройства. Их лучше передать владельцу отдельно и изменить после ввода в эксплуатацию.
\end{tcolorbox}

\subsection{Двусторонний обмен через ntfy}
Помимо исходящих уведомлений прошивка периодически опрашивает тот же ntfy topic (примерно один раз в 15~с) и принимает только безопасные read-only команды состояния:
\begin{center}
\texttt{!ups} \qquad \texttt{!ups status} \qquad \texttt{!ups ping}
\end{center}
Команды \texttt{!ups} и \texttt{!ups status} вызывают отправку полного статуса. Команда \texttt{!ups ping} возвращает сообщение ``PONG'' и тот же набор параметров. В ответ включаются напряжение АКБ, напряжение 24~В, состояние сети, ROUTER/ONT, интернет, recovery, uptime, число отключений, RSSI, IP и mDNS-адрес.

Удалённые команды включения/выключения выходов через ntfy \textbf{не реализованы}. Это сделано намеренно: topic используется только как канал чтения статуса. Команды работают только когда ESP32 бодрствует, подключена к Wi-Fi и имеет доступ к ntfy. В Shelf Sleep и во время аварийного сна Wi-Fi выключен, поэтому команды недоступны.

\begin{tcolorbox}[colback=lightaccent,colframe=accent,title=Безопасность ntfy]
Имя topic фактически является секретным адресом. Использовать длинное, трудноугадываемое имя и не печатать его на наружной наклейке устройства.
\end{tcolorbox}

\subsection{Доступные функции веб-панели}
\begin{itemize}[leftmargin=7mm]
  \item напряжение АКБ и 24-В линии;
  \item наличие сети;
  \item отдельное состояние ROUTER и ONT;
  \item режимы ON / OFF / AUTO каждого канала;
  \item отдельный restart ROUTER и restart ONT;
  \item совместный restart обоих выходов;
  \item состояние Wi-Fi и RSSI;
  \item состояние проверки интернета и autorecovery;
  \item состояние аварийного deep sleep и его параметры;
  \item справка по Shelf Sleep и сервисной кнопке;
  \item калибровка ADC по мультиметру;
  \item настройка Wi-Fi, ntfy и защитных порогов;
  \item справка по входящим ntfy-командам;
  \item журнал событий;
  \item ручная перезагрузка ESP32.
\end{itemize}

% -------------------- 6 --------------------
\section{Алгоритм автоматического восстановления связи}

Прошивка различает потерю Wi-Fi и потерю доступа в интернет. Типовая логика:
\begin{enumerate}[leftmargin=8mm]
  \item Если ESP32 не подключена к Wi-Fi после допустимого времени ожидания, выполняется попытка восстановить соединение.
  \item При устойчивой неисправности Wi-Fi первым перезапускается канал ROUTER.
  \item Если Wi-Fi присутствует, но интернет недоступен, первым перезапускается канал ONT.
  \item При продолжении неисправности допускается следующий цикл восстановления, включая совместный power-cycle обоих каналов.
  \item Количество автоматических power-cycle ограничено, чтобы исключить бесконечное переключение оборудования.
  \item После длительного периода стабильной связи счётчики autorecovery сбрасываются.
  \item При низком АКБ автоматические перезапуски блокируются, чтобы не расходовать остаточный заряд.
\end{enumerate}

% -------------------- 7 --------------------
\section{Установка и ввод в эксплуатацию}

\subsection{Предварительная проверка}
Перед первым включением или после обслуживания:
\begin{enumerate}[leftmargin=8mm]
  \item Проверить полярность аккумулятора.
  \item Проверить наличие и номинал предохранителя АКБ.
  \item Проверить отсутствие незакреплённых проводов и токоведущих частей.
  \item Мультиметром выставить и проверить выходное напряжение каждого XL6009 \textbf{до подключения нагрузки}.
  \item Убедиться, что полярность DC-разъёмов соответствует подключаемому оборудованию.
  \item Проверить, что напряжение ROUTER и ONT записано в паспорт и на шильдик.
  \item Подать 230~В и проконтролировать напряжение на клеммах АКБ.
  \item Проверить переход на аккумулятор кратковременным отключением 230~В.
\end{enumerate}

\subsection{Контрольное испытание перед передачей}
\begin{tabularx}{\textwidth}{@{}XcX@{}}
\toprule
\textbf{Проверка} & \textbf{Результат} & \textbf{Примечание} \\
\midrule
Напряжение заряда АКБ 13,8~В & \yesno & \rule{40mm}{0.4pt} \\
ROUTER ON/OFF/AUTO & \yesno & \rule{40mm}{0.4pt} \\
ONT ON/OFF/AUTO & \yesno & \rule{40mm}{0.4pt} \\
Restart ROUTER из веб-панели & \yesno & \rule{40mm}{0.4pt} \\
Restart ONT из веб-панели & \yesno & \rule{40mm}{0.4pt} \\
Переход сеть $\rightarrow$ АКБ & \yesno & \rule{40mm}{0.4pt} \\
LVD & \yesno & \rule{40mm}{0.4pt} \\
Аварийный deep sleep и периодические wake-up & \yesno & \rule{40mm}{0.4pt} \\
Возврат сети после аварийного deep sleep & \yesno & \rule{40mm}{0.4pt} \\
Shelf Sleep: вход удержанием 10~с & \yesno & \rule{40mm}{0.4pt} \\
Shelf Sleep: wake только кнопкой & \yesno & \rule{40mm}{0.4pt} \\
Кнопка: 1x status / 2x setup AP & \yesno & \rule{40mm}{0.4pt} \\
Wi-Fi / mDNS & \yesno & \rule{40mm}{0.4pt} \\
ntfy: исходящие уведомления & \yesno & \rule{40mm}{0.4pt} \\
ntfy: \texttt{!ups status} / \texttt{!ups ping} & \yesno & \rule{40mm}{0.4pt} \\
Нагрузочное испытание обоих каналов & \yesno & \rule{40mm}{0.4pt} \\
\bottomrule
\end{tabularx}

% -------------------- 8 --------------------
\section{Разборка и замена аккумулятора}

\begin{tcolorbox}[colback=lightwarn,colframe=warn,title=Опасное напряжение]
Перед снятием крышки обязательно отключить устройство от 230~В, отсоединить сетевой шнур, отключить нагрузку и разомкнуть цепь аккумулятора. Даже при отключённой сети аккумулятор остаётся источником энергии и способен выдавать высокий ток короткого замыкания.
\end{tcolorbox}

\subsection{Порядок разборки}
\begin{enumerate}[leftmargin=8mm]
  \item Отключить 230~В и убедиться, что сетевой ввод физически отсоединён.
  \item Выключить внешние нагрузки ROUTER и ONT.
  \item Снять крышку согласно рисункам в разделе~\ref{sec:figures}.
  \item Отключить предохранитель / разъём аккумулятора.
  \item Первой отсоединить клемму, указанную в сервисной схеме конкретной сборки; не допускать контакта инструмента между ``+'' и корпусом/``-''.
  \item Отсоединить вторую клемму и извлечь аккумулятор.
  \item Установить новый AGM/SLA аккумулятор 12~В 7~А\,ч совместимого размера и типа клемм.
  \item Подключить полярность строго по маркировке: красный провод к ``+'', чёрный к ``-''.
  \item Вернуть предохранитель, проверить напряжение мультиметром и собрать корпус.
  \item Выполнить контрольный переход сеть $\rightarrow$ АКБ.
\end{enumerate}

\subsection{Требования к аккумулятору-замене}
\begin{itemize}[leftmargin=7mm]
  \item номинальное напряжение 12~В;
  \item технология AGM/SLA (герметичный свинцово-кислотный);
  \item номинальная ёмкость 7~А\,ч либо другая, допускаемая корпусом и зарядным режимом;
  \item совместимые габариты, расположение клемм и тип наконечников;
  \item отсутствие вздутия, трещин и следов утечки.
\end{itemize}

\subsection{Сервисные изображения и 3D-модель}\label{sec:figures}
Сборочные виды экспортированы из общедоступной модели Onshape (см. подраздел о 3D-модели в README проекта). Полные STEP-файлы лежат в каталоге репозитория \texttt{hardware/enclosure/step/}.

\realfig{exploded-front.png}{Рисунок 1. Разнесённый вид со стороны лицевой панели: корпус из алюминиевого профиля, аккумулятор AGM~12\,В\,7\,А·ч установлен внутри, лицевая панель с входным разъёмом IEC~C14, силовым выключателем и двумя гнёздами DC-выходов вынесена слева.}

\realfig{exploded-rear.png}{Рисунок 2. Разнесённый вид со стороны задней панели: корпус с уже установленными органами управления, задняя крышка снята, показана двухъярусная плата с зарядным модулем XL4016, двумя DC/DC XL6009 и материнской платой ESP32.}

% -------------------- 9 --------------------
\section{Техническое обслуживание}

Рекомендуемая периодичность проверки: один раз в 3--6 месяцев, а также после длительного отключения сети или заметного сокращения автономности.

\begin{itemize}[leftmargin=7mm]
  \item визуальный осмотр корпуса и кабелей;
  \item проверка отсутствия нагрева, запаха, потемнений и деформации компонентов;
  \item проверка затяжки клемм при отключённом питании;
  \item проверка напряжения заряда на клеммах АКБ;
  \item проверка напряжения обоих выходов;
  \item тест работы от АКБ;
  \item проверка LVD и восстановления;
  \item проверка состояния аккумулятора и даты его установки;
  \item проверка журнала событий и исходящих ntfy-уведомлений;
  \item проверка ответа на \texttt{!ups status};
  \item проверка входа в Shelf Sleep и пробуждения кнопкой.
\end{itemize}

\subsection{Ожидаемый срок службы АКБ}
Срок службы герметичного свинцово-кислотного аккумулятора зависит от температуры, глубины и частоты разрядов и качества поддерживающего заряда. Аккумулятор является расходным элементом и подлежит замене при существенном снижении фактической автономности, деформации корпуса или нестабильном напряжении под нагрузкой.

% -------------------- 10 --------------------
\section{Возможные неисправности}
\begin{longtable}{@{}p{38mm}p{48mm}p{74mm}@{}}
\toprule
\textbf{Признак} & \textbf{Возможная причина} & \textbf{Действия} \\
\midrule
\endhead
Нет питания на обоих выходах & Режим OFF, LVD, отсутствует АКБ, предохранитель, неисправность общей шины & Проверить веб-панель, напряжение АКБ, предохранитель и клеммы \\
Нет ROUTER & Выключен канал 1, механический выключатель, XL6009 канала 1, силовой ключ & Проверить режим ROUTER и напряжение до/после соответствующего DC/DC \\
Нет ONT & Выключен канал 2, механический выключатель, XL6009 канала 2, силовой ключ & Проверить режим ONT и напряжение до/после соответствующего DC/DC \\
Нет веб-панели & ESP не подключилась к Wi-Fi либо роутер отключён & Использовать сервисную кнопку, setup AP и Serial при обслуживании \\
Wi-Fi есть, интернета нет & Сбой ONT/провайдера/WAN & Проверить журнал; устройство может выполнить автоматический restart ONT \\
Быстро разряжается АКБ & Старение АКБ или увеличившаяся нагрузка & Измерить ток/мощность нагрузки и выполнить тест ёмкости \\
Система ушла в deep sleep & Низкий АКБ после LVD при отсутствии сети & Восстановить 230~В и дождаться ближайшей периодической проверки \\
Устройство не включилось после подачи 230~В & Оно находится в Shelf Sleep / режиме хранения & Нажать сервисную кнопку; сеть 230~В намеренно не является источником wake-up в этом режиме \\
Кнопка дала 3 красных мигания & Не удалось отправить статус в ntfy & Проверить Wi-Fi, интернет и настройку topic; само устройство продолжает работать \\
Команда \texttt{!ups status} не отвечает & Устройство спит, нет Wi-Fi/интернета или неверный topic & Разбудить устройство при необходимости, проверить Wi-Fi и topic; команды опрашиваются примерно раз в 15~с \\
Выходное напряжение проседает & Перегрузка XL6009, плохой контакт, силовой ключ или проводка & Снять нагрузку, измерить напряжение по узлам, проверить ток и нагрев \\
\bottomrule
\end{longtable}

% -------------------- 11 --------------------
\section{Комплект поставки}
\begin{tabularx}{\textwidth}{@{}clXc@{}}
\toprule
№ & \textbf{Наименование} & \textbf{Примечание} & \textbf{Кол.} \\
\midrule
1 & DC-UPS-2CH & Основной блок & 1 \\
2 & АКБ 12~В 7~А\,ч AGM/SLA & Установлен в корпус & 1 \\
3 & Паспорт и руководство & Настоящий документ & 1 \\
4 & Гарантийный талон & В составе документа & 1 \\
5 & Кабели питания выходов & \rule{55mm}{0.4pt} & \rule{10mm}{0.4pt} \\
6 & Прочее & \rule{55mm}{0.4pt} & \rule{10mm}{0.4pt} \\
\bottomrule
\end{tabularx}

% -------------------- 12 --------------------
\section{Свидетельство о приёмке}
Изделие DC-UPS-2CH \hwversion, серийный номер \rule{50mm}{0.4pt}, собрано, проверено и признано годным к эксплуатации при соблюдении настоящего руководства.

\vspace{5mm}
\begin{tabular}{@{}p{55mm}p{90mm}@{}}
Дата изготовления: & \rule{65mm}{0.4pt} \\
Дата проверки: & \rule{65mm}{0.4pt} \\
Проверил: & \rule{65mm}{0.4pt} \\
Подпись: & \rule{65mm}{0.4pt} \\
\end{tabular}

% -------------------- 13 --------------------
\newpage
\section{Гарантийный талон}

\begin{tcolorbox}[colback=white,colframe=accent,boxrule=1pt,arc=2mm]
\begin{tabular}{@{}p{55mm}p{90mm}@{}}
Изделие: & DC-UPS-2CH \hwversion \\
Серийный номер: & \rule{65mm}{0.4pt} \\
Дата передачи: & \rule{65mm}{0.4pt} \\
Изготовитель / сборщик: & \rule{65mm}{0.4pt} \\
Владелец: & \rule{65mm}{0.4pt} \\
Гарантийный срок: & \rule{30mm}{0.4pt} месяцев \\
\end{tabular}
\end{tcolorbox}

\subsection*{Гарантия распространяется}
На дефекты сборки и отказ внутренних узлов изделия при соблюдении условий эксплуатации, если иное письменно не оговорено при передаче.

\subsection*{Гарантия не распространяется}
\begin{itemize}[leftmargin=7mm]
  \item на естественное старение и потерю ёмкости аккумулятора;
  \item на повреждения вследствие переполюсовки, короткого замыкания или подключения нагрузки с неверным напряжением;
  \item на перегрузку выходов сверх записанных в паспорте значений;
  \item на попадание воды, конденсат, пожар, грозовые и иные внешние воздействия;
  \item на механические повреждения;
  \item на последствия самостоятельной переделки силовой части или изменения настроек, выходящих за согласованные пределы;
  \item на неисправности внешнего роутера, ONT, сети провайдера и подключённых кабелей.
\end{itemize}

\subsection*{Отметки о ремонте}
\begin{tabularx}{\textwidth}{@{}p{25mm}Xp{35mm}@{}}
\toprule
\textbf{Дата} & \textbf{Выполненные работы} & \textbf{Подпись} \\
\midrule
\rule{0pt}{10mm} & & \\
\midrule
\rule{0pt}{10mm} & & \\
\midrule
\rule{0pt}{10mm} & & \\
\bottomrule
\end{tabularx}

\vfill
\begin{tabular}{@{}p{72mm}p{72mm}@{}}
Подпись изготовителя: \rule{35mm}{0.4pt} & Подпись владельца: \rule{35mm}{0.4pt} \\
\end{tabular}

% -------------------- 14 --------------------
\newpage
\section{Краткая памятка владельцу}
\begin{enumerate}[leftmargin=8mm]
  \item В штатном режиме устройство не требует ручного переключения между сетью и АКБ.
  \item При отключении 230~В работа продолжается от аккумулятора до достижения порога защиты.
  \item После LVD устройство отключает нагрузку и переходит в аварийный deep sleep для сохранения аккумулятора.
  \item После возврата сети устройство автоматически выходит из \textbf{аварийного} deep sleep, включает разрешённые выходы и восстанавливает Wi-Fi.
  \item Панель: \texttt{http://dc-ups.local/}.
  \item Кнопка: 1 короткое -- отправить статус в ntfy; 2 коротких -- setup AP на 15 минут; удержание 10~с -- Shelf Sleep.
  \item В Shelf Sleep устройство просыпается \textbf{только кнопкой}; подача 230~В сама по себе его не включает.
  \item Запрос статуса через ntfy: \texttt{!ups}, \texttt{!ups status} или \texttt{!ups ping}.
  \item Перед подключением нового оборудования проверить требуемое напряжение и полярность.
  \item Не вскрывать корпус при подключённой сети 230~В или подключённом аккумуляторе.
\end{enumerate}

\begin{center}
\vfill
\qrcode[height=28mm]{http://dc-ups.local/}\\[2mm]
{\small Быстрый переход к локальной панели (работает из той же локальной сети при поддержке mDNS).}
\end{center}

\end{document}

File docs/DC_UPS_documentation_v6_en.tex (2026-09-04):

\documentclass[11pt,a4paper]{article}

\usepackage{fontspec}
\setmainfont{DejaVu Serif}
\setsansfont{DejaVu Sans}
\setmonofont{DejaVu Sans Mono}
\usepackage[english]{babel}
\usepackage{geometry}
\geometry{left=20mm,right=20mm,top=18mm,bottom=20mm}
\usepackage{microtype}
\usepackage{array,tabularx,longtable,booktabs,multirow}
\usepackage{enumitem}
\usepackage{graphicx}
% Renders exported from the Onshape model live next to the STEP files.
\graphicspath{{../hardware/enclosure/renders/}}
\usepackage{xcolor}
\usepackage{hyperref}
\usepackage{fancyhdr}
\usepackage{titlesec}
\usepackage{lastpage}
\usepackage{tcolorbox}
\usepackage{caption}
\usepackage{float}
\usepackage{qrcode}
\usepackage{tikz}
\usetikzlibrary{positioning}

% Build identity is normally injected by `make -C docs build_info`.
% Fallbacks below let the .tex compile standalone in a TeX editor without make.
\IfFileExists{build_info.tex}{\input{build_info}}{%
  \newcommand{\hwversion}{v2.1}%
  \newcommand{\fwversion}{dev}%
  \newcommand{\builddate}{unknown}%
  \newcommand{\buildcommit}{unknown}%
  \newcommand{\docrev}{unknown}%
}

\hypersetup{colorlinks=true,linkcolor=black,urlcolor=blue,pdfauthor={DC-UPS-2CH manufacturer},pdftitle={DC-UPS-2CH technical passport and user manual \fwversion}}
\setlength{\parindent}{0pt}
\setlength{\parskip}{0.45em}
\renewcommand{\arraystretch}{1.2}

\definecolor{accent}{HTML}{1E5B4F}
\definecolor{lightaccent}{HTML}{EAF3F1}
\definecolor{warn}{HTML}{8B1E1E}
\definecolor{lightwarn}{HTML}{F9ECEC}

\titleformat{\section}{\Large\bfseries\color{accent}}{\thesection.}{0.5em}{}
\titleformat{\subsection}{\large\bfseries}{\thesubsection.}{0.5em}{}
\titleformat{\subsubsection}{\normalsize\bfseries}{\thesubsubsection.}{0.5em}{}

\pagestyle{fancy}
\fancyhf{}
\lhead{DC-UPS-2CH}
\rhead{Passport and user manual}
\cfoot{Page \thepage}
\renewcommand{\headrulewidth}{0.4pt}
\setlength{\headheight}{14pt}

\newcommand{\fieldline}[1]{\textbf{#1}: \rule{0.55\linewidth}{0.4pt}}
\newcommand{\blankfig}[2]{%
  \begin{figure}[H]\centering
  \fbox{\parbox[c][#1][c]{0.90\textwidth}{\centering\sffamily\color{gray}\Large #2\\[0.5em]\normalsize Insert screenshot / image}}
  \end{figure}
}
% \realfig{filename}{caption} — inserts an image full text-width with a caption line.
\newcommand{\realfig}[2]{%
  \begin{figure}[H]\centering
  \\[0.4em]
  {\sffamily\small #2}
  \end{figure}
}
\newcommand{\yesno}{□~yes\quad □~no}

\begin{document}

% -------------------- TITLE --------------------
\begin{titlepage}
\centering
\vspace*{18mm}
{\sffamily\bfseries\fontsize{28}{34}\selectfont DC-UPS-2CH\\[3mm]}
{\sffamily\Large Backup power supply for networking equipment\\[12mm]}

\begin{tcolorbox}[width=0.85\textwidth,colback=lightaccent,colframe=accent,boxrule=0.8pt,arc=2mm]
\centering
{\Large\bfseries TECHNICAL PASSPORT\\
USER MANUAL\\
SERVICE INSTRUCTIONS\\
WARRANTY CARD}
\end{tcolorbox}

\vfill
\begin{tabular}{@{}p{55mm}p{90mm}@{}}
Model: & DC-UPS-2CH \hwversion \\
Firmware version: & \fwversion \\
Document revision: & \builddate\ / \docrev \\
Serial number: & \rule{70mm}{0.4pt} \\
Date of manufacture: & \rule{70mm}{0.4pt} \\
Manufacturer / integrator: & \rule{70mm}{0.4pt} \\
Contact: & \rule{70mm}{0.4pt} \\
\end{tabular}

\vfill
{\small This document is intended for the owner of the unit and for scheduled maintenance.\\
Keep together with the device. Applies to firmware \fwversion\ (build \buildcommit, \builddate).}
\end{titlepage}

\tableofcontents
\newpage

% -------------------- 1 --------------------
\section{General information}

\subsection{Purpose}
DC-UPS-2CH is a dual-channel DC backup power supply for networking and low-current equipment. The device is intended to keep a Wi-Fi router, an ONT / optical terminal, a modem or any other compatible load running when 230~V mains is interrupted.

The unit combines an internal 24~V AC/DC brick, a charge converter, a sealed 12~V battery, two independent output DC/DC channels and an ESP32 controller. The controller monitors mains and battery, drives the two outputs, keeps an event log, performs automatic connectivity recovery and exposes a web interface.

\subsection{Main functions}
\begin{itemize}[leftmargin=7mm]
  \item automatic mains-to-battery transition without manual switching;
  \item float charging with a current limit;
  \item two independent managed output channels: ROUTER and ONT;
  \item low-voltage disconnect protection (LVD) for the battery;
  \item emergency deep sleep for the controller after the load is dropped;
  \item periodic mains-return probe during emergency deep sleep;
  \item separate Shelf Sleep mode: both outputs and Wi-Fi off, wake only by physical button;
  \item Wi-Fi and internet reachability monitoring;
  \item automatic power-cycle of output channels on connectivity failure;
  \item local web interface;
  \item mDNS address \texttt{http://dc-ups.local/};
  \item service access point \texttt{DC-UPS-Setup};
  \item ntfy push notifications;
  \item read-only commands through the same ntfy topic: \texttt{!ups}, \texttt{!ups status}, \texttt{!ups ping};
  \item RAM event log with persistent tail across reboots;
  \item local tact button: status, setup AP and Shelf Sleep;
  \item mains and battery indication LEDs.
\end{itemize}

\begin{tcolorbox}[colback=lightwarn,colframe=warn,title=Important]
Dangerous 230~V mains voltage is present inside the enclosure. Disassembly, adjustment and replacement of internal components are only permitted with the mains supply and the battery disconnected.
\end{tcolorbox}

% -------------------- 2 --------------------
\section{Technical specifications}

\subsection{Main parameters}
\begin{longtable}{@{}p{70mm}p{80mm}@{}}
\toprule
\textbf{Parameter} & \textbf{Value} \\
\midrule
\endhead
Product type & Dual-channel DC UPS for low-current equipment \\
Mains input & 230~V AC, 50~Hz \\
Intermediate bus & 24~V DC from the internal AC/DC module \\
Battery rating & 12~V, 7~Ah, sealed AGM/SLA \\
Installed battery model & \rule{60mm}{0.4pt} \\
Float charge voltage & 13.8~V at the battery terminals (trimmable) \\
Charge current limit & 1.5~A \\
Charger DC/DC module & XL4016 CC/CV or an installed equivalent \\
Number of outputs & 2 independent channels \\
Output DC/DC modules & 2\,$\times$\,XL6009 buck-boost or an installed equivalent \\
Controller & ESP32 \\
Firmware version at release & \fwversion \\
Battery sensing & ADC, GPIO35, divider 100~k$\Omega$ / 10~k$\Omega$ \\
24~V rail sensing & ADC, GPIO34, divider 100~k$\Omega$ / 10~k$\Omega$ \\
ROUTER channel & GPIO32 $\rightarrow$ NPN 2N2222 $\rightarrow$ P-MOSFET \\
ONT channel & GPIO25 $\rightarrow$ NPN 2N2222 $\rightarrow$ P-MOSFET \\
Service button & GPIO14, short to GND, INPUT\_PULLUP; RTC GPIO / EXT0 wake in Shelf Sleep \\
Mains LED & GPIO13 \\
Battery / fault LED & GPIO12 \\
P-MOSFET gate pull-up & 10~k$\Omega$ gate--source (per the current schematic) \\
P-MOSFET model & IRF9Zxx / actually installed: \rule{35mm}{0.4pt} \\
Battery fuse & recommended 5~A, mounted directly at the positive terminal \\
\bottomrule
\end{longtable}

\subsection{Output parameters for this unit}
\begin{tabularx}{\textwidth}{@{}lXccc@{}}
\toprule
\textbf{Channel} & \textbf{Purpose / connected device} & \textbf{U, V} & \textbf{I nom, A} & \textbf{I max, A} \\
\midrule
ROUTER & \rule{45mm}{0.4pt} & \rule{12mm}{0.4pt} & \rule{12mm}{0.4pt} & \rule{12mm}{0.4pt} \\
ONT & \rule{45mm}{0.4pt} & \rule{12mm}{0.4pt} & \rule{12mm}{0.4pt} & \rule{12mm}{0.4pt} \\
\bottomrule
\end{tabularx}

\begin{tcolorbox}[colback=lightaccent,colframe=accent,title=Note on output current]
The maximum permissible current of each output is determined by the actual DC/DC module installed, its cooling, wiring, connectors and the P-MOSFET. Before handover the values must be established from a load test and recorded both in the table above and on the enclosure label. Do not use the ``advertised maximum'' of the XL6009 module as the label value.
\end{tcolorbox}

\subsection{Protection thresholds}
\begin{tabularx}{\textwidth}{@{}XlX@{}}
\toprule
\textbf{Function} & \textbf{Default} & \textbf{Purpose} \\
\midrule
Battery early warning & 11.5~V & Notification of an approaching discharge \\
LVD / load disconnect & 11.0~V & Cuts ROUTER and ONT when mains is absent \\
Post-LVD recovery & 12.5~V & Allows re-enable after battery recovery \\
Fallback low-voltage sleep & 10.8~V & Second layer of low-voltage protection \\
Delay before deep sleep & 30~s & Time to finish notifications and settle state \\
Wake period in emergency sleep & 30~s & Checks 24~V rail and battery state \\
Shelf Sleep / storage mode & no periodic timer & Wake only by GPIO14 button (EXT0) \\
``Mains present'' hysteresis high & above 15.0~V on the 24~V rail & Upper hysteresis threshold \\
``Mains lost'' hysteresis low & below 10.0~V on the 24~V rail & Lower hysteresis threshold \\
Mains debounce & 3~s & Suppresses spurious transitions \\
\bottomrule
\end{tabularx}

All values above (except hardware-fixed ones) can be changed from the web interface. The values in this document match firmware defaults.

% -------------------- 3 --------------------
\section{Structure and principle of operation}

\subsection{Simplified block diagram}
\begin{center}
\begin{tikzpicture}[scale=0.78,transform shape,>=latex, node distance=7mm and 7mm, every node/.style={font=\sffamily\small}]
\node[draw,rounded corners,minimum width=28mm,minimum height=10mm] (ac) {230 V AC};
\node[draw,rounded corners,right=of ac,minimum width=32mm,minimum height=10mm] (psu) {AC/DC 24 V};
\node[draw,rounded corners,right=of psu,minimum width=34mm,minimum height=10mm] (chg) {XL4016 CC/CV};
\node[draw,rounded corners,right=of chg,minimum width=30mm,minimum height=10mm] (bus) {13.8 V / battery};
\node[draw,rounded corners,below=12mm of bus,minimum width=30mm,minimum height=10mm] (bat) {AGM 12 V 7 Ah};
\node[draw,rounded corners,below left=18mm and 15mm of bus,minimum width=36mm,minimum height=10mm] (r) {P-MOSF 1 + XL6009};
\node[draw,rounded corners,below right=18mm and 15mm of bus,minimum width=36mm,minimum height=10mm] (o) {P-MOSF 2 + XL6009};
\node[draw,rounded corners,below=13mm of r,minimum width=28mm,minimum height=9mm] (rr) {ROUTER};
\node[draw,rounded corners,below=13mm of o,minimum width=28mm,minimum height=9mm] (oo) {ONT / AUX};
\node[draw,rounded corners,below=35mm of bus,minimum width=34mm,minimum height=10mm,fill=lightaccent] (esp) {ESP32};
\draw[->] (ac)--(psu); \draw[->] (psu)--(chg); \draw[->] (chg)--(bus); \draw[<->] (bus)--(bat);
\draw[->] (bus)--(r); \draw[->] (bus)--(o); \draw[->] (r)--(rr); \draw[->] (o)--(oo);
\draw[->,dashed] (esp)--node[left]{GPIO32}(r); \draw[->,dashed] (esp)--node[right]{GPIO25}(o);
\draw[->,dashed] (bus)--node[right]{ADC}(esp);
\end{tikzpicture}
\end{center}

\subsection{Normal mode}
With mains present the internal AC/DC module produces 24~V. The XL4016 charger steps it down and holds the battery-side bus at the trimmed 13.8~V with a total current limit of 1.5~A. The load and the battery are powered from a shared bus behind a blocking diode according to the specific build.

\subsection{Battery mode}
When the 24~V rail collapses the battery automatically becomes the source for the shared bus. No separate transfer relay is required. The controller detects the mains loss, keeps the enabled channels powered and sends a notification if a network path is available.

\subsection{Deep-discharge protection}
While running on battery the controller compares the battery voltage with the configured thresholds. When LVD is reached both outputs are shut off. Re-enable is not allowed until either the recovery threshold is reached or the mains returns.

After LVD and load release, the controller waits the configured delay and then enters \textbf{emergency deep sleep}. The controller does not wait for a second dip on the unloaded battery ``bounce''. In this mode the ESP32 only wakes on a timer to measure battery voltage and the 24~V rail. Full boot happens only when the mains returns or when the battery recovers above the re-enable threshold.

\subsection{Two sleep modes}
\textbf{Emergency deep sleep} is entered automatically on low battery with the mains absent. Both outputs are off, Wi-Fi is off, the controller wakes on a timer (30~s by default), quickly measures the battery and the 24~V rail, and sleeps again if recovery conditions are not met.

\textbf{Shelf Sleep} is entered only from a long service-button hold. Both outputs, Wi-Fi, mDNS and the setup AP are shut down and the wake-up timer is disabled. The only wake source is the physical button on GPIO14 via EXT0. Restoring 230~V mains \textbf{does not} bring the device out of Shelf Sleep --- the button must be pressed.

% -------------------- 4 --------------------
\section{Controls and indication}

\subsection{LEDs}
\begin{tabularx}{\textwidth}{@{}lX@{}}
\toprule
\textbf{Indicator} & \textbf{Purpose} \\
\midrule
Green, GPIO13 & Indicates external power / mains state \\
Red, GPIO12 & Indicates battery state, warning or emergency mode \\
\bottomrule
\end{tabularx}

Additional patterns:
\begin{itemize}
  \item green blinking at $\approx$2~Hz --- the ESP32 has booted and is trying to join Wi-Fi;
  \item both LEDs alternating slowly (500~ms each) --- the setup AP is active.
\end{itemize}

\subsection{Service button on GPIO14}
The button is wired between GPIO14 and GND. The internal \texttt{INPUT\_PULLUP} is used in normal operation. GPIO14 is chosen because it is also an RTC GPIO usable for EXT0 wake from Shelf Sleep.

\begin{tabularx}{\textwidth}{@{}p{38mm}X@{}}
\toprule
\textbf{Gesture} & \textbf{Function} \\
\midrule
One short press & Send the full current status to the configured ntfy topic. On success the green LED blinks 2 times; if Wi-Fi / ntfy is unreachable the red LED blinks 3 times. \\
Double press & Open \texttt{DC-UPS-Setup} for about 15 minutes. Acknowledged by a short simultaneous flash of both LEDs. \\
Hold for 10~s & Enter Shelf Sleep. Before shutdown the red LED blinks 3 times; then ROUTER and ONT are shut off, Wi-Fi goes down and the ESP32 sleeps with no periodic timer. \\
Press while in Shelf Sleep & Wake the device. The held press is ignored until release, after which a normal start-up runs. \\
\bottomrule
\end{tabularx}

\begin{tcolorbox}[colback=lightwarn,colframe=warn,title=Important: Shelf Sleep]
In Shelf Sleep the device \textbf{does not} wake on the return of 230~V mains. It intentionally stays off until the button is physically pressed. This is a long-term storage / transport mode, not an emergency battery mode.
\end{tcolorbox}

\subsection{Manual output switches}
If separate mechanical switches for ROUTER and ONT are installed on the enclosure, they act as local hardware disconnects for the corresponding output. Their state has priority at the electrical level: software cannot restore power while a mechanical switch is open.

% -------------------- 5 --------------------
\section{Web interface and networking}

\subsection{Access}
With a normal LAN connection the panel is available at:
\begin{center}
\texttt{http://dc-ups.local/}
\end{center}
It is also reachable at the IP address issued by the router. On every successful Wi-Fi connection the firmware may publish the current IP to ntfy.

\subsection{Service access point}
Default SSID: \texttt{DC-UPS-Setup}.\\
Default password: \texttt{dc-ups-setup}.\\
Both parameters can be changed by the owner through the web interface.

\begin{tcolorbox}[colback=lightaccent,colframe=accent,title=Recommendation]
The setup-AP password and the web admin password should not be printed on the outside label. Deliver them separately and change them at commissioning.
\end{tcolorbox}

\subsection{Bidirectional ntfy}
In addition to outgoing notifications the firmware polls the same ntfy topic periodically (roughly every 15~s) and accepts only safe, read-only status commands:
\begin{center}
\texttt{!ups} \qquad \texttt{!ups status} \qquad \texttt{!ups ping}
\end{center}
The \texttt{!ups} and \texttt{!ups status} commands send the full status. The \texttt{!ups ping} command answers with ``PONG'' and the same set of parameters. The reply includes battery voltage, 24~V rail, mains state, ROUTER/ONT, internet, recovery, uptime, outage count, RSSI, IP and the mDNS address.

Remote enable/disable of the outputs through ntfy is \textbf{not implemented} on purpose: the topic is intentionally a read-only status channel. Commands only work while the ESP32 is awake, connected to Wi-Fi and has access to ntfy. In Shelf Sleep and in emergency deep sleep the Wi-Fi radio is off, so commands are unavailable.

\begin{tcolorbox}[colback=lightaccent,colframe=accent,title=ntfy security]
The topic name is effectively a secret URL. Use a long, hard-to-guess name and do not print it on the outside label.
\end{tcolorbox}

\subsection{Available panel features}
\begin{itemize}[leftmargin=7mm]
  \item battery voltage and 24~V rail;
  \item mains presence;
  \item ROUTER and ONT states separately;
  \item ON / OFF / AUTO mode per channel;
  \item independent restart of ROUTER and restart of ONT;
  \item joint restart of both channels;
  \item Wi-Fi state and RSSI;
  \item internet-check state and auto-recovery status;
  \item emergency-sleep state and parameters;
  \item Shelf Sleep and service-button reference;
  \item ADC calibration against a multimeter;
  \item Wi-Fi, ntfy and protection settings;
  \item help on inbound ntfy commands;
  \item event log;
  \item manual ESP32 reboot.
\end{itemize}

% -------------------- 6 --------------------
\section{Automatic connectivity recovery}

The firmware distinguishes between Wi-Fi loss and loss of internet reachability. Typical logic:
\begin{enumerate}[leftmargin=8mm]
  \item If the ESP32 is not associated with Wi-Fi after the allowed waiting period, a reconnect is attempted.
  \item On persistent Wi-Fi failure the ROUTER channel is power-cycled first.
  \item If Wi-Fi is up but the internet is unreachable, the ONT channel is power-cycled first.
  \item On continued failure the next recovery cycle is allowed, including a joint power-cycle of both channels.
  \item The number of automatic power cycles is capped to avoid endless equipment toggling.
  \item After a long period of stable connectivity the auto-recovery counters are reset.
  \item On low battery all automatic power cycles are inhibited to preserve residual charge.
\end{enumerate}

% -------------------- 7 --------------------
\section{Installation and commissioning}

\subsection{Pre-flight}
Before the first power-up or after servicing:
\begin{enumerate}[leftmargin=8mm]
  \item Check the battery polarity.
  \item Check the presence and rating of the battery fuse.
  \item Check that no wires and no live parts are loose.
  \item With a multimeter, set and verify the output voltage of every XL6009 \textbf{before} connecting a load.
  \item Confirm that the DC connector polarity matches the connected equipment.
  \item Confirm that the ROUTER and ONT voltages are recorded in the passport and on the label.
  \item Apply 230~V and check the voltage at the battery terminals.
  \item Verify the mains-to-battery transition by briefly disconnecting 230~V.
\end{enumerate}

\subsection{Acceptance test before handover}
\begin{tabularx}{\textwidth}{@{}XcX@{}}
\toprule
\textbf{Check} & \textbf{Result} & \textbf{Note} \\
\midrule
Battery charge voltage 13.8~V & \yesno & \rule{40mm}{0.4pt} \\
ROUTER ON/OFF/AUTO & \yesno & \rule{40mm}{0.4pt} \\
ONT ON/OFF/AUTO & \yesno & \rule{40mm}{0.4pt} \\
Restart ROUTER from the panel & \yesno & \rule{40mm}{0.4pt} \\
Restart ONT from the panel & \yesno & \rule{40mm}{0.4pt} \\
Mains $\rightarrow$ battery transition & \yesno & \rule{40mm}{0.4pt} \\
LVD & \yesno & \rule{40mm}{0.4pt} \\
Emergency deep sleep and periodic wake-ups & \yesno & \rule{40mm}{0.4pt} \\
Mains return after emergency deep sleep & \yesno & \rule{40mm}{0.4pt} \\
Shelf Sleep: entry by 10~s hold & \yesno & \rule{40mm}{0.4pt} \\
Shelf Sleep: wake only by button & \yesno & \rule{40mm}{0.4pt} \\
Button: 1x status / 2x setup AP & \yesno & \rule{40mm}{0.4pt} \\
Wi-Fi / mDNS & \yesno & \rule{40mm}{0.4pt} \\
ntfy: outgoing notifications & \yesno & \rule{40mm}{0.4pt} \\
ntfy: \texttt{!ups status} / \texttt{!ups ping} & \yesno & \rule{40mm}{0.4pt} \\
Load test on both channels & \yesno & \rule{40mm}{0.4pt} \\
\bottomrule
\end{tabularx}

% -------------------- 8 --------------------
\section{Disassembly and battery replacement}

\begin{tcolorbox}[colback=lightwarn,colframe=warn,title=Hazardous voltage]
Before removing the cover always disconnect the unit from 230~V mains, unplug the mains cord, disconnect the load and open the battery circuit. Even with the mains removed the battery remains an energy source capable of delivering high short-circuit currents.
\end{tcolorbox}

\subsection{Procedure}
\begin{enumerate}[leftmargin=8mm]
  \item Disconnect 230~V and make sure the mains inlet is physically detached.
  \item Turn off the external ROUTER and ONT loads.
  \item Remove the cover following the illustrations in Section~\ref{sec:figures}.
  \item Remove the battery fuse or connector.
  \item First disconnect the terminal called out by the service diagram of the specific build; keep the tool from bridging ``+'' to the case / ``-''.
  \item Disconnect the second terminal and take the battery out.
  \item Install a new AGM/SLA battery 12~V 7~Ah of a compatible size and terminal type.
  \item Connect polarity strictly by the marking: red cable to ``+'', black cable to ``-''.
  \item Reinstall the fuse, check the voltage with a multimeter, and reassemble the enclosure.
  \item Perform a control mains $\rightarrow$ battery transition.
\end{enumerate}

\subsection{Replacement battery requirements}
\begin{itemize}[leftmargin=7mm]
  \item nominal voltage 12~V;
  \item AGM/SLA (sealed lead-acid) technology;
  \item nominal capacity 7~Ah or another value permitted by the enclosure and the charge regime;
  \item compatible dimensions, terminal layout and terminal type;
  \item no bulging, cracks or leakage marks.
\end{itemize}

\subsection{Service images and 3D model}\label{sec:figures}
Assembly views are exported from the public Onshape model (see the 3D-model subsection in the project README). The full STEP files live in \texttt{hardware/enclosure/step/} in the repository.

\realfig{exploded-front.png}{Figure~1. Exploded view --- front side: aluminium extrusion enclosure, AGM 12~V 7~Ah battery installed inside, front panel with IEC~C14 mains inlet, power switch and two DC output receptacles displaced to the left.}

\realfig{exploded-rear.png}{Figure~2. Exploded view --- rear side: enclosure with the controls installed, rear panel removed, two-tier PCB assembly with the XL4016 charger, two XL6009 DC/DC modules and the ESP32 board displayed.}

\blankfig{55mm}{Figure 3. Cover fasteners / clips and disassembly direction}
\blankfig{55mm}{Figure 4. Position of the fuse and battery terminals}
\blankfig{55mm}{Figure 5. Removal and installation of the battery}
\blankfig{55mm}{Figure 6. Close-up of XL4016, ESP32, both XL6009 and the power channels}

% -------------------- 9 --------------------
\section{Maintenance}

Recommended interval: once every 3--6 months, and additionally after any prolonged outage or after the autonomous runtime shortens noticeably.

\begin{itemize}[leftmargin=7mm]
  \item visual inspection of the enclosure and cabling;
  \item check for heat, smell, discoloration or component deformation;
  \item terminal-torque check with the unit de-energised;
  \item battery charge voltage at the terminals;
  \item voltage on both outputs;
  \item battery-mode test;
  \item LVD and recovery test;
  \item check battery condition and installation date;
  \item review the event log and outgoing ntfy notifications;
  \item verify the reply to \texttt{!ups status};
  \item verify Shelf Sleep entry and button wake.
\end{itemize}

\subsection{Expected battery service life}
The life of a sealed lead-acid battery depends on temperature, depth and frequency of discharge and the quality of the float charge. The battery is a consumable and must be replaced when the actual autonomous runtime drops significantly, when the case deforms or when the terminal voltage becomes unstable under load.

% -------------------- 10 --------------------
\section{Troubleshooting}
\begin{longtable}{@{}p{38mm}p{48mm}p{74mm}@{}}
\toprule
\textbf{Symptom} & \textbf{Possible cause} & \textbf{Action} \\
\midrule
\endhead
No power on either output & OFF mode, LVD, missing battery, fuse or shared-bus failure & Check the web panel, battery voltage, fuse and terminals \\
No ROUTER & Channel 1 off, mechanical switch, channel-1 XL6009 or power stage & Check ROUTER mode and voltage before/after the corresponding DC/DC \\
No ONT & Channel 2 off, mechanical switch, channel-2 XL6009 or power stage & Check ONT mode and voltage before/after the corresponding DC/DC \\
Web panel not reachable & ESP failed to join Wi-Fi or the router is off & Use the service button, the setup AP and the serial port for diagnostics \\
Wi-Fi up, no internet & ONT / provider / WAN fault & Check the log; the device may automatically restart ONT \\
Battery discharges fast & Ageing battery or increased load & Measure the load current / power and run a capacity test \\
System went into deep sleep & Low battery after LVD with no mains & Restore 230~V and wait for the next periodic probe \\
Device did not start after 230~V was restored & Shelf Sleep is active & Press the service button; 230~V is intentionally not a wake source in this mode \\
Button caused 3 red blinks & Status could not be sent to ntfy & Check Wi-Fi, internet and topic configuration; the device continues to operate \\
\texttt{!ups status} does not reply & Device is sleeping, no Wi-Fi/internet or wrong topic & Wake the device if necessary; check Wi-Fi and topic; commands are polled about once every 15~s \\
Output voltage sags & XL6009 overload, poor contact, power stage or wiring & Remove the load, measure voltage across the chain, check current and heat \\
\bottomrule
\end{longtable}

% -------------------- 11 --------------------
\section{Package contents}
\begin{tabularx}{\textwidth}{@{}clXc@{}}
\toprule
\# & \textbf{Item} & \textbf{Note} & \textbf{Qty} \\
\midrule
1 & DC-UPS-2CH & Main unit & 1 \\
2 & Battery 12~V 7~Ah AGM/SLA & Installed in the enclosure & 1 \\
3 & Passport and user manual & This document & 1 \\
4 & Warranty card & Part of this document & 1 \\
5 & Output power cables & \rule{55mm}{0.4pt} & \rule{10mm}{0.4pt} \\
6 & Other & \rule{55mm}{0.4pt} & \rule{10mm}{0.4pt} \\
\bottomrule
\end{tabularx}

% -------------------- 12 --------------------
\section{Certificate of acceptance}
The DC-UPS-2CH \hwversion\ unit, serial number \rule{50mm}{0.4pt}, has been assembled, tested and found fit for operation subject to compliance with this manual.

\vspace{5mm}
\begin{tabular}{@{}p{55mm}p{90mm}@{}}
Date of manufacture: & \rule{65mm}{0.4pt} \\
Date of inspection: & \rule{65mm}{0.4pt} \\
Inspected by: & \rule{65mm}{0.4pt} \\
Signature: & \rule{65mm}{0.4pt} \\
\end{tabular}

% -------------------- 13 --------------------
\newpage
\section{Warranty card}

\begin{tcolorbox}[colback=white,colframe=accent,boxrule=1pt,arc=2mm]
\begin{tabular}{@{}p{55mm}p{90mm}@{}}
Product: & DC-UPS-2CH \hwversion \\
Serial number: & \rule{65mm}{0.4pt} \\
Date of transfer: & \rule{65mm}{0.4pt} \\
Manufacturer / integrator: & \rule{65mm}{0.4pt} \\
Owner: & \rule{65mm}{0.4pt} \\
Warranty period: & \rule{30mm}{0.4pt} months \\
\end{tabular}
\end{tcolorbox}

\subsection*{The warranty covers}
Manufacturing defects and internal component failures under compliance with the operating conditions, unless stated otherwise in writing at handover.

\subsection*{The warranty does not cover}
\begin{itemize}[leftmargin=7mm]
  \item natural ageing and capacity loss of the battery;
  \item damage caused by reverse polarity, short circuits or connection of loads with wrong voltage;
  \item overloads beyond the ratings recorded in the passport;
  \item water ingress, condensation, fire, lightning or other external influence;
  \item mechanical damage;
  \item consequences of unauthorised modification of the power section or of settings beyond agreed limits;
  \item faults of the external router, ONT, provider network and connected cabling.
\end{itemize}

\subsection*{Repair record}
\begin{tabularx}{\textwidth}{@{}p{25mm}Xp{35mm}@{}}
\toprule
\textbf{Date} & \textbf{Work performed} & \textbf{Signature} \\
\midrule
\rule{0pt}{10mm} & & \\
\midrule
\rule{0pt}{10mm} & & \\
\midrule
\rule{0pt}{10mm} & & \\
\bottomrule
\end{tabularx}

\vfill
\begin{tabular}{@{}p{72mm}p{72mm}@{}}
Manufacturer's signature: \rule{35mm}{0.4pt} & Owner's signature: \rule{35mm}{0.4pt} \\
\end{tabular}

% -------------------- 14 --------------------
\newpage
\section{Quick reference for the owner}
\begin{enumerate}[leftmargin=8mm]
  \item Under normal conditions no manual switching between mains and battery is needed.
  \item On mains loss operation continues from the battery until the protection threshold is reached.
  \item After LVD the device drops the load and enters emergency deep sleep to preserve the battery.
  \item After mains return the device automatically exits \textbf{emergency} deep sleep, enables the allowed outputs and restores Wi-Fi.
  \item Panel: \texttt{http://dc-ups.local/}.
  \item Button: 1 short --- status to ntfy; 2 shorts --- setup AP for 15 minutes; hold 10~s --- Shelf Sleep.
  \item In Shelf Sleep the device wakes \textbf{only from the button}; restoring 230~V does not turn it on.
  \item Status query through ntfy: \texttt{!ups}, \texttt{!ups status} or \texttt{!ups ping}.
  \item Before connecting new equipment verify the required voltage and polarity.
  \item Do not open the enclosure while 230~V mains or the battery is connected.
\end{enumerate}

\begin{center}
\vfill
\qrcode[height=28mm]{http://dc-ups.local/}\\[2mm]
{\small Quick jump to the local panel (works from the same LAN with mDNS support).}
\end{center}

\end{document}

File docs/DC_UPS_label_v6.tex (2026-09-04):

\documentclass[tikz,border=0pt]{standalone}
\usepackage{fontspec}
\setsansfont{DejaVu Sans}
\setmonofont{DejaVu Sans Mono}
\usepackage{xcolor}
\usepackage{qrcode}
\usetikzlibrary{matrix}

% -----------------------------------------------------------------------------
% DC-UPS-2CH identification label (RU)
% Physical size: 90 x 55 mm
% Recommended print scale: 100 % / Actual size
% -----------------------------------------------------------------------------

\definecolor{accent}{HTML}{153F37}
\definecolor{text}{HTML}{171C1A}
\definecolor{muted}{HTML}{66716D}
\definecolor{line}{HTML}{AAB5B1}
\definecolor{soft}{HTML}{EEF2F0}

\newcommand{\docurl}{https://mrzlohex.github.io/dc-ups-2ch/}

\IfFileExists{build_info.tex}{\input{build_info}}{%
  \newcommand{\hwversion}{v2.1}%
  \newcommand{\fwversion}{v6}%
  \newcommand{\builddate}{}%
  \newcommand{\buildcommit}{}%
  \newcommand{\docrev}{}%
}

\begin{document}
\begin{tikzpicture}[x=1mm,y=1mm]
  \useasboundingbox (0,0) rectangle (90,55);

  % Background and frame
  \fill[white] (0,0) rectangle (90,55);
  \draw[line width=0.45pt,color=text] (1.1,1.1) rectangle (88.9,53.9);

  % Header
  \fill[accent] (1.1,45.4) rectangle (88.9,53.9);
  \node[anchor=west,text=white,
        font=\sffamily\bfseries\fontsize{13.7}{14}\selectfont,
        text height=2.35ex,text depth=.25ex]
    at (3.4,49.65) {DC-UPS-2CH};
  \node[anchor=east,text=white,
        font=\ttfamily\fontsize{6.5}{7}\selectfont,
        text height=1.7ex,text depth=.3ex]
    at (86.6,49.65) {HW \hwversion\quad FW \fwversion};

  % Classification
  \node[anchor=north west,text=text,
        font=\sffamily\bfseries\fontsize{5.85}{6.35}\selectfont,
        text height=1.7ex,text depth=.25ex]
    at (3.4,44.0) {ДВУХКАНАЛЬНЫЙ ИБП ПОСТОЯННОГО ТОКА};

  % Electrical data
  \matrix (specs) [
    matrix of nodes,
    anchor=north west,
    nodes={
      anchor=base west,
      inner sep=0pt,
      outer sep=0pt,
      text height=1.55ex,
      text depth=.35ex
    },
    row sep=0.15mm,
    column sep=7.0mm
  ] at (5.4,38.5) {
    |[text=muted,font=\sffamily\bfseries\fontsize{5.55}{6.15}\selectfont]| ВХОД
      & |[text=text,font=\ttfamily\fontsize{5.9}{6.25}\selectfont]| 230V AC  50Hz \\
    |[text=muted,font=\sffamily\bfseries\fontsize{5.55}{6.15}\selectfont]| АКБ
      & |[text=text,font=\ttfamily\fontsize{5.9}{6.25}\selectfont]| 12V  7Ah AGM/SLA \\
    |[text=muted,font=\sffamily\bfseries\fontsize{5.55}{6.15}\selectfont]| ЗАРЯД
      & |[text=text,font=\ttfamily\fontsize{5.9}{6.25}\selectfont]| 13.8V  1.5A max \\
    |[text=muted,font=\sffamily\bfseries\fontsize{5.55}{6.15}\selectfont]| ВЫХОД 1
      & |[text=text,font=\ttfamily\fontsize{5.72}{6.2}\selectfont]|  \rule{7.0mm}{0.32pt}\,V\quad \rule{5.4mm}{0.32pt}\,A \\
    |[text=muted,font=\sffamily\bfseries\fontsize{5.55}{6.15}\selectfont]| ВЫХОД 2
      & |[text=text,font=\ttfamily\fontsize{5.72}{6.2}\selectfont]|  \rule{7.0mm}{0.32pt}\,V\quad \rule{5.4mm}{0.32pt}\,A \\
    |[text=muted,font=\sffamily\bfseries\fontsize{5.55}{6.15}\selectfont]| ЛОКАЛ. UI
      & |[text=text,font=\ttfamily\fontsize{5.72}{6.2}\selectfont]| dc-ups.local \\
  };

  % QR / documentation block
  \draw[line width=0.28pt,color=line] (64.2,17.5) -- (64.2,43.55);

  \node[anchor=north,inner sep=0pt] at (76.3,41.0)
    {\qrcode[height=17.2mm]{\docurl}};
  \node[anchor=north,align=center,text=text,
        font=\sffamily\bfseries\fontsize{5.4}{5.85}\selectfont,
        text height=1.55ex,text depth=.25ex]
    at (76.3,23.0) {ДОКУМЕНТАЦИЯ};

  % Identification separator and fields
  \draw[line width=0.25pt,color=line] (3.4,15.5) -- (86.6,15.5);

  \node[anchor=base west,text=muted,
        font=\sffamily\bfseries\fontsize{5.4}{5.9}\selectfont,
        text height=1.55ex,text depth=.3ex]
    at (3.4,11.2) {S/N};
  \draw[line width=0.32pt,color=text] (9.0,11.0) -- (34.0,11.0);

  \node[anchor=base west,text=muted,
        font=\sffamily\bfseries\fontsize{5.4}{5.9}\selectfont,
        text height=1.55ex,text depth=.3ex]
    at (39.2,11.2) {ДАТА};
  \draw[line width=0.32pt,color=text] (48.0,11.0) -- (64.2,11.0);

  % Button reference strip
  \fill[soft] (3.4,3.0) rectangle (86.6,8.0);
  \draw[line width=0.25pt,color=line] (3.4,3.0) rectangle (86.6,8.0);

  \node[anchor=base west,text=accent,
        font=\sffamily\bfseries\fontsize{5.45}{6}\selectfont,
        text height=1.55ex,text depth=.3ex]
    at (5.0,4.8) {КНОПКА};
  \node[anchor=base west,text=text,
        font=\ttfamily\fontsize{4.85}{5.4}\selectfont,
        text height=1.55ex,text depth=.3ex]
    at (25.0,4.8) {1x СТАТУС \quad| \quad 2x SETUP \quad| \quad УДЕРЖ. 10 с - ХРАНЕНИЕ};

\end{tikzpicture}
\end{document}

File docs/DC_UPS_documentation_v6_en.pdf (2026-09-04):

# DC-UPS-2CH

## Backup power supply for networking equipment

## TECHNICAL PASSPORT USER MANUAL SERVICE INSTRUCTIONS WARRANTY CARD

Model: | DC-UPS-2CH v2.1
Firmware version: | 2026.09.02-v6
Document revision: | 2026-09-04 / 190fc6b
Serial number:
Date of manufacture:
Manufacturer / integrator:
Contact:

This document is intended for the owner of the unit and for scheduled maintenance. Keep together with the device. Applies to firmware 2026.09.02-v6 (build 190fc6b, 2026-09-04).

DC-UPS-2CH | Passport and user manual

## Contents

1 General information | 3
2 Technical specifications | 4
3 Structure and principle of operation | 5
4 Controls and indication | 6
5 Web interface and networking | 7
6 Automatic connectivity recovery | 9
7 Installation and commissioning | 9
8 Disassembly and battery replacement | 10
9 Maintenance | 13

10Troubleshooting | 14
11Package contents | 15
12Certificate of acceptance | 15
13Warranty card | 16
14Quick reference for the owner | 17

## 1. General information

### 1.1. Purpose

DC-UPS-2CH is a dual-channel DC backup power supply for networking and low-current equipment. The device is intended to keep a Wi-Fi router, an ONT / optical terminal, a modem or any other compatible load running when 230 V mains is interrupted.
The unit combines an internal 24 V AC/DC brick, a charge converter, a sealed 12 V battery, two independent output DC/DC channels and an ESP32 controller. The controller monitors mains and battery, drives the two outputs, keeps an event log, performs automatic connectivity recovery and exposes a web interface.

### 1.2. Main functions

- automatic mains-to-battery transition without manual switching;
- float charging with a current limit;
- two independent managed output channels: ROUTER and ONT;
- low-voltage disconnect protection (LVD) for the battery;
- emergency deep sleep for the controller after the load is dropped;
- periodic mains-return probe during emergency deep sleep;
- separate Shelf Sleep mode: both outputs and Wi-Fi off, wake only by physical button;
- Wi-Fi and internet reachability monitoring;
- automatic power-cycle of output channels on connectivity failure;
- local web interface;
- mDNS address http://dc-ups.local/;
- service access point DC-UPS-Setup;
- ntfy push notifications;
- read-only commands through the same ntfy topic: !ups, !ups status, !ups ping;
- RAM event log with persistent tail across reboots;
- local tact button: status, setup AP and Shelf Sleep;
- mains and battery indication LEDs.

Important

Dangerous 230 V mains voltage is present inside the enclosure. Disassembly, adjustment and replacement of internal components are only permitted with the mains supply and the battery disconnected.

## 2. Technical specifications

### 2.1. Main parameters

Parameter | Value
Product type | Dual-channel DC UPS for low-current
equipment
Mains input | 230 V AC, 50 Hz
Intermediate bus | 24 V DC from the internal AC/DC module
Battery rating | 12 V, 7 Ah, sealed AGM/SLA
Installed battery model
Float charge voltage | 13.8 | V | at | the | battery | terminals
(trimmable)
Charge current limit | 1.5 A
Charger DC/DC module | XL4016 CC/CV or an installed equivalent
Number of outputs | 2 independent channels
Output DC/DC modules | 2 × XL6009 buck-boost or an installed
equivalent
Controller | ESP32
Firmware version at release | 2026.09.02-v6
Battery sensing | ADC, GPIO35, divider 100 kΩ / 10 kΩ
24 V rail sensing | ADC, GPIO34, divider 100 kΩ / 10 kΩ
ROUTER channel | GPIO32 → NPN 2N2222 → P-MOSFET
ONT channel | GPIO25 → NPN 2N2222 → P-MOSFET
Service button | GPIO14, short to GND, INPUT_PULLUP;
RTC GPIO / EXT0 wake in Shelf Sleep
Mains LED | GPIO13
Battery / fault LED | GPIO12
P-MOSFET gate pull-up | 10 kΩ gate–source (per the current
schematic)
P-MOSFET model | IRF9Zxx | / | actually | installed:
Battery fuse | recommended 5 A, mounted directly at
the positive terminal

### 2.2. Output parameters for this unit

Channel Purpose / connected device | U, V | I nom, A I max, A

ROUTER
ONT

Note on output current

The maximum permissible current of each output is determined by the actual DC/DC module installed, its cooling, wiring, connectors and the P-MOSFET. Before handover the values must be established from a load test and recorded both in the table above and on the enclosure label. Do not use the “advertised maximum” of the XL6009 module as the label value.

### 2.3. Protection thresholds

Function | Default | Purpose
Battery early warning | 11.5 V | Notification | of | an | ap-
proaching discharge
LVD / load disconnect | 11.0 V | Cuts ROUTER and ONT
when mains is absent
Post-LVD recovery | 12.5 V | Allows re-enable after bat-
tery recovery
Fallback low-voltage sleep | 10.8 V | Second | layer | of | low-
voltage protection
Delay before deep sleep | 30 s | Time to finish notifications
and settle state
Wake period in emergency
sleep
30 s | Checks 24 V rail and bat-
tery state
Shelf Sleep / storage mode no periodic timer | Wake only by GPIO14 but-
ton (EXT0)
“Mains present” hysteresis
high

above 15.0 V on the 24 V rail Upper hysteresis threshold

“Mains lost” hysteresis low below 10.0 V on the 24 V rail Lower hysteresis threshold
Mains debounce | 3 s | Suppresses spurious tran-
sitions

All values above (except hardware-fixed ones) can be changed from the web interface. The values in this document match firmware defaults.

## 3. Structure and principle of operation

### 3.1. Simplified block diagram

230 V AC | AC/DC 24 V | XL4016 CC/CV | 13.8 V / battery
AGM 12 | V 7 Ah
P-MOSF 1 + XL6009 | P-MOSF 2 + XL6009
ROUTER | ONT / AUX

ESP32

GPIO32 | GPIO25

ADC

### 3.2. Normal mode

With mains present the internal AC/DC module produces 24 V. The XL4016 charger steps it down and holds the battery-side bus at the trimmed 13.8 V with a total current limit of 1.5 A. The load and the battery are powered from a shared bus behind a blocking diode according to the specific build.

### 3.3. Battery mode

When the 24 V rail collapses the battery automatically becomes the source for the shared bus. No separate transfer relay is required. The controller detects the mains loss, keeps the enabled channels powered and sends a notification if a network path is available.

### 3.4. Deep-discharge protection

While running on battery the controller compares the battery voltage with the configured thresholds. When LVD is reached both outputs are shut off. Re-enable is not allowed until either the recovery threshold is reached or the mains returns.
After LVD and load release, the controller waits the configured delay and then enters emergency deep sleep. The controller does not wait for a second dip on the unloaded battery “bounce”. In this mode the ESP32 only wakes on a timer to measure battery voltage and the 24 V rail. Full boot happens only when the mains returns or when the battery recovers above the re-enable threshold.

### 3.5. Two sleep modes

Emergency deep sleep is entered automatically on low battery with the mains absent. Both outputs are off, Wi-Fi is off, the controller wakes on a timer (30 s by default), quickly measures the battery and the 24 V rail, and sleeps again if recovery conditions are not met.
Shelf Sleep is entered only from a long service-button hold. Both outputs, Wi-Fi, mDNS and the setup AP are shut down and the wake-up timer is disabled. The only wake source is the physical button on GPIO14 via EXT0. Restoring 230 V mains does not bring the device out of Shelf Sleep — the button must be pressed.

## 4. Controls and indication

### 4.1. LEDs

Indicator | Purpose

Green, GPIO13 Indicates external power / mains state
Red, GPIO12 Indicates battery state, warning or emergency mode

Additional patterns:

- green blinking at ≈2 Hz — the ESP32 has booted and is trying to join Wi-Fi;
- both LEDs alternating slowly (500 ms each) — the setup AP is active.

### 4.2. Service button on GPIO14

The button is wired between GPIO14 and GND. The internal INPUT_PULLUP is used in normal operation. GPIO14 is chosen because it is also an RTC GPIO usable for EXT0 wake from Shelf Sleep.

Gesture | Function
One short press | Send the full current status to the configured ntfy topic. On suc- cess the green LED blinks 2 times; if Wi-Fi / ntfy is unreachable the red LED blinks 3 times.
Double press | Open DC-UPS-Setup for about 15 minutes. Acknowledged by a short simultaneous flash of both LEDs.
Hold for 10 s | Enter Shelf Sleep. Before shutdown the red LED blinks 3 times; then ROUTER and ONT are shut off, Wi-Fi goes down and the ESP32 sleeps with no periodic timer.
Press while in Shelf Sleep | Wake the device. The held press is ignored until release, after which a normal start-up runs.

Important: Shelf Sleep

In Shelf Sleep the device does not wake on the return of 230 V mains. It intentionally stays off until the button is physically pressed. This is a long-term storage / transport mode, not an emergency battery mode.

### 4.3. Manual output switches

If separate mechanical switches for ROUTER and ONT are installed on the enclosure, they act as local hardware disconnects for the corresponding output. Their state has priority at the electrical level: software cannot restore power while a mechanical switch is open.

## 5. Web interface and networking

### 5.1. Access

With a normal LAN connection the panel is available at:

http://dc-ups.local/

It is also reachable at the IP address issued by the router. On every successful Wi-Fi connection the firmware may publish the current IP to ntfy.

### 5.2. Service access point

Default SSID: DC-UPS-Setup.
Default password: dc-ups-setup.
Both parameters can be changed by the owner through the web interface.

Recommendation

The setup-AP password and the web admin password should not be printed on the outside label. Deliver them separately and change them at commissioning.

### 5.3. Bidirectional ntfy

In addition to outgoing notifications the firmware polls the same ntfy topic periodically (roughly every 15 s) and accepts only safe, read-only status commands:

!ups | !ups status | !ups ping

The !ups and !ups status commands send the full status. The !ups ping command answers with “PONG” and the same set of parameters. The reply includes battery voltage, 24 V rail, mains state, ROUTER/ONT, internet, recovery, uptime, outage count, RSSI, IP and the mDNS address.
Remote enable/disable of the outputs through ntfy is not implemented on purpose: the topic is intentionally a read-only status channel. Commands only work while the ESP32 is awake, connected to Wi-Fi and has access to ntfy. In Shelf Sleep and in emergency deep sleep the Wi-Fi radio is off, so commands are unavailable.

ntfy security

The topic name is effectively a secret URL. Use a long, hard-to-guess name and do not print it on the outside label.

### 5.4. Available panel features

- battery voltage and 24 V rail;
- mains presence;
- ROUTER and ONT states separately;
- ON / OFF / AUTO mode per channel;
- independent restart of ROUTER and restart of ONT;
- joint restart of both channels;
- Wi-Fi state and RSSI;
- internet-check state and auto-recovery status;
- emergency-sleep state and parameters;
- Shelf Sleep and service-button reference;
- ADC calibration against a multimeter;
- Wi-Fi, ntfy and protection settings;
- help on inbound ntfy commands;
- event log;
- manual ESP32 reboot.

## 6. Automatic connectivity recovery

The firmware distinguishes between Wi-Fi loss and loss of internet reachability. Typical logic:

1. If the ESP32 is not associated with Wi-Fi after the allowed waiting period, a reconnect is attempted.
2. On persistent Wi-Fi failure the ROUTER channel is power-cycled first.
3. If Wi-Fi is up but the internet is unreachable, the ONT channel is power-cycled first.
4. On continued failure the next recovery cycle is allowed, including a joint power-cycle of both channels.
5. The number of automatic power cycles is capped to avoid endless equipment toggling.
6. After a long period of stable connectivity the auto-recovery counters are reset.
7. On low battery all automatic power cycles are inhibited to preserve residual charge.

## 7. Installation and commissioning

### 7.1. Pre-flight

Before the first power-up or after servicing:

1. Check the battery polarity.
2. Check the presence and rating of the battery fuse.
3. Check that no wires and no live parts are loose.
4. With a multimeter, set and verify the output voltage of every XL6009 before connecting a load.
5. Confirm that the DC connector polarity matches the connected equipment.
6. Confirm that the ROUTER and ONT voltages are recorded in the passport and on the label.
7. Apply 230 V and check the voltage at the battery terminals.
8. Verify the mains-to-battery transition by briefly disconnecting 230 V.

### 7.2. Acceptance test before handover

Check | Result | Note
Battery charge voltage 13.8 V | □ yes □ no
ROUTER ON/OFF/AUTO | □ yes □ no
ONT ON/OFF/AUTO | □ yes □ no
Restart ROUTER from the panel | □ yes □ no
Restart ONT from the panel | □ yes □ no
Mains → battery transition | □ yes □ no
LVD | □ yes □ no
Emergency deep sleep and periodic wake-ups | □ yes □ no
Mains return after emergency deep sleep | □ yes □ no
Shelf Sleep: entry by 10 s hold | □ yes □ no
Shelf Sleep: wake only by button | □ yes □ no
Button: 1x status / 2x setup AP | □ yes □ no
Wi-Fi / mDNS | □ yes □ no
ntfy: outgoing notifications | □ yes □ no
ntfy: !ups status / !ups ping | □ yes □ no
Load test on both channels | □ yes □ no

## 8. Disassembly and battery replacement

Hazardous voltage

Before removing the cover always disconnect the unit from 230 V mains, unplug the mains cord, disconnect the load and open the battery circuit. Even with the mains removed the battery remains an energy source capable of delivering high short-circuit currents.

### 8.1. Procedure

1. Disconnect 230 V and make sure the mains inlet is physically detached.
2. Turn off the external ROUTER and ONT loads.
3. Remove the cover following the illustrations in Section 8.3.
4. Remove the battery fuse or connector.
5. First disconnect the terminal called out by the service diagram of the specific build; keep the tool from bridging “+” to the case / “-”.
6. Disconnect the second terminal and take the battery out.
7. Install a new AGM/SLA battery 12 V 7 Ah of a compatible size and terminal type.
8. Connect polarity strictly by the marking: red cable to “+”, black cable to “-”.

9. Reinstall the fuse, check the voltage with a multimeter, and reassemble the enclosure.
10. Perform a control mains → battery transition.

### 8.2. Replacement battery requirements

- nominal voltage 12 V;
- AGM/SLA (sealed lead-acid) technology;
- nominal capacity 7 Ah or another value permitted by the enclosure and the charge regime;
- compatible dimensions, terminal layout and terminal type;
- no bulging, cracks or leakage marks.

### 8.3. Service images and 3D model

Assembly views are exported from the public Onshape model (see the 3D-model subsection in the project README). The full STEP files live in hardware/enclosure/step/ in the repository.

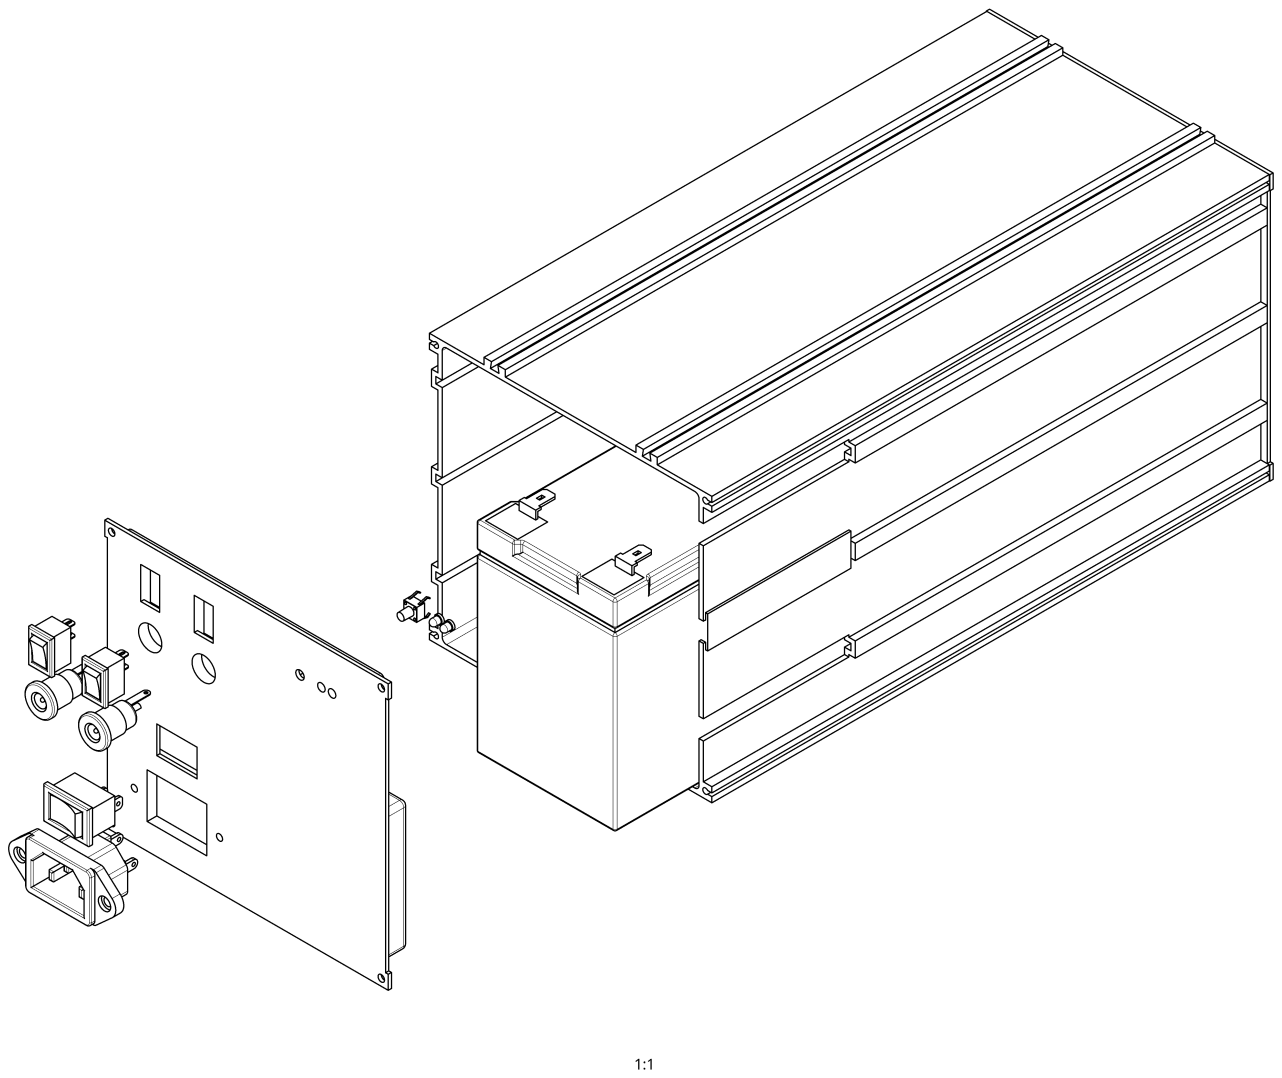
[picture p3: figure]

Figure 1. Exploded view — front side: aluminium extrusion enclosure, AGM 12 V 7 Ah battery installed inside, front panel with IEC C14 mains inlet, power switch and two DC output receptacles displaced to the left.

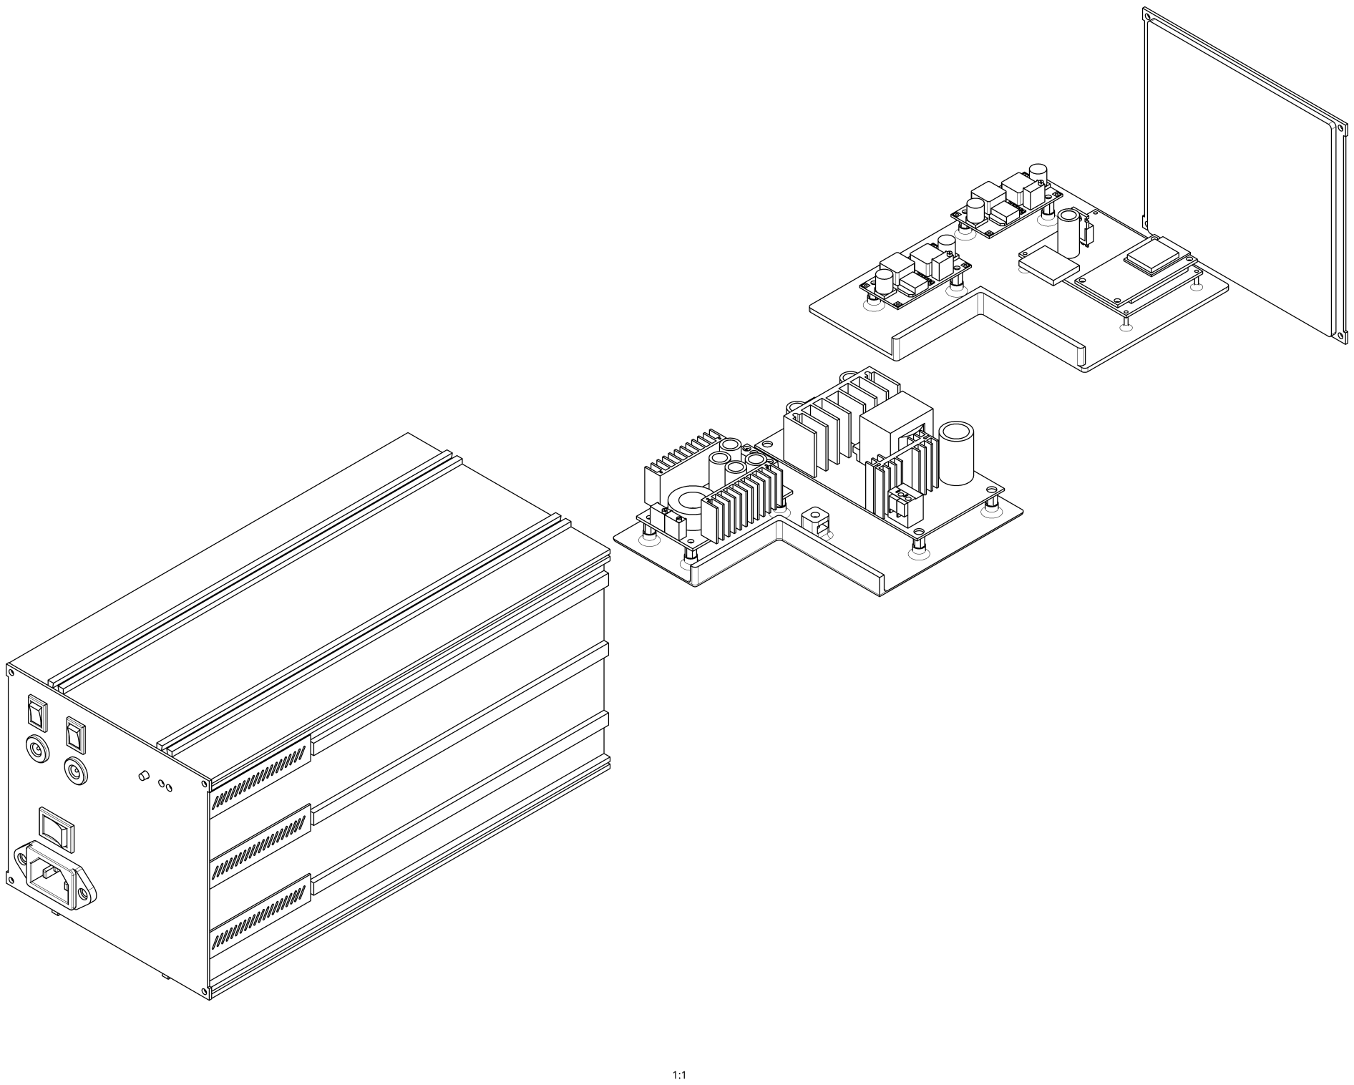
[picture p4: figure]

Figure 2. Exploded view — rear side: enclosure with the controls installed, rear panel removed, two-tier PCB assembly with the XL4016 charger, two XL6009 DC/DC modules and the ESP32 board displayed.

## Figure 3. Cover fasteners / clips and disassembly direction

Insert screenshot / image

## Figure 4. Position of the fuse and battery terminals

Insert screenshot / image

## Figure 5. Removal and installation of the battery

Insert screenshot / image

## Figure 6. Close-up of XL4016, ESP32, both XL6009 and the power channels

Insert screenshot / image

## 9. Maintenance

Recommended interval: once every 3–6 months, and additionally after any prolonged outage or after the autonomous runtime shortens noticeably.

- visual inspection of the enclosure and cabling;
- check for heat, smell, discoloration or component deformation;
- terminal-torque check with the unit de-energised;
- battery charge voltage at the terminals;

- voltage on both outputs;
- battery-mode test;
- LVD and recovery test;
- check battery condition and installation date;
- review the event log and outgoing ntfy notifications;
- verify the reply to !ups status;
- verify Shelf Sleep entry and button wake.

### 9.1. Expected battery service life

The life of a sealed lead-acid battery depends on temperature, depth and frequency of discharge and the quality of the float charge. The battery is a consumable and must be replaced when the actual autonomous runtime drops significantly, when the case deforms or when the terminal voltage becomes unstable under load.
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

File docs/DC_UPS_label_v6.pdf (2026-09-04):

DC-UPS-2CH | HW v2.1 FW 2026.09.02-v6

ДВУХКАНАЛЬНЫЙ ИБП ПОСТОЯННОГО ТОКА

ВХОД | 230V AC 50Hz
АКБ | 12V 7Ah AGM/SLA
ЗАРЯД | 13.8V 1.5A max
ВЫХОД 1 | V | A
ВЫХОД 2 | V | A
ЛОКАЛ. UI | dc-ups.local | ДОКУМЕНТАЦИЯ
S/N | ДАТА
КНОПКА | 1x СТАТУС | | | 2x SETUP | | | УДЕРЖ. 10 с - ХРАНЕНИЕ

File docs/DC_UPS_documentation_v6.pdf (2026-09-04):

# DC-UPS-2CH

## Источник резервного питания сетевого оборудования

## ПАСПОРТ ИЗДЕЛИЯ РУКОВОДСТВО ПО ЭКСПЛУАТАЦИИ СЕРВИСНАЯ ИНСТРУКЦИЯ ГАРАНТИЙНЫЙ ТАЛОН

Модель изделия: | DC-UPS-2CH v2.1
Версия прошивки: | 2026.09.02-v6
Редакция документа: | 2026-09-04 / 190fc6b
Серийный номер:
Дата изготовления:
Изготовитель / сборщик:
Контакт:

Документ предназначен для владельца изделия и для выполнения регламентного обслуживания.
Хранить вместе с устройством. Актуализировано для прошивки 2026.09.02-v6 (сборка 190fc6b, 2026-09-04).

DC-UPS-2CH | Паспорт и руководство
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

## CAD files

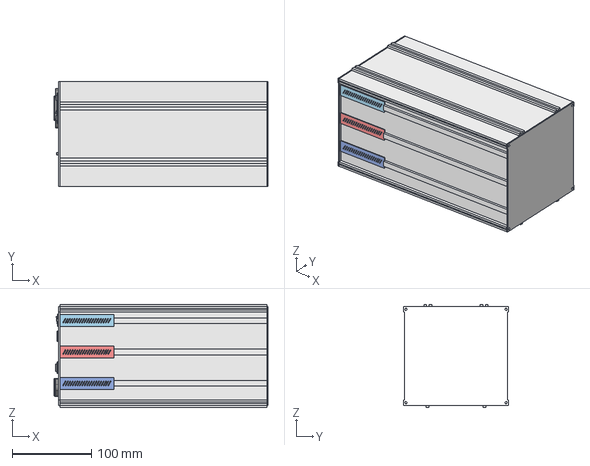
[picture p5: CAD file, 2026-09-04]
hardware/enclosure/step/Main.step
269.4 x 132.5 x 130.0 mm

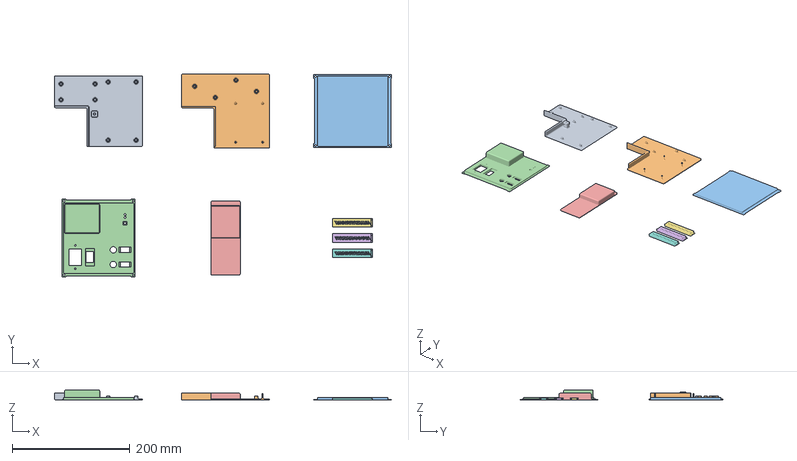
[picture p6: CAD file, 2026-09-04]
hardware/enclosure/3mf/DC_UPS.3mf
573.2 x 345.2 x 17.5 mm

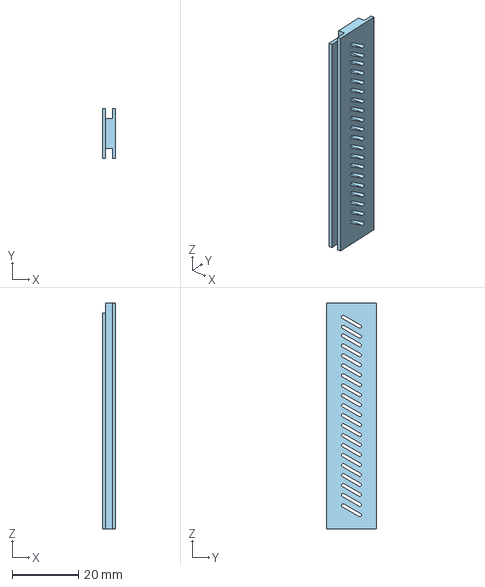
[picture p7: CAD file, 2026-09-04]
hardware/enclosure/step/Dummy Sky.step
4.05 x 15.0 x 68.0 mm

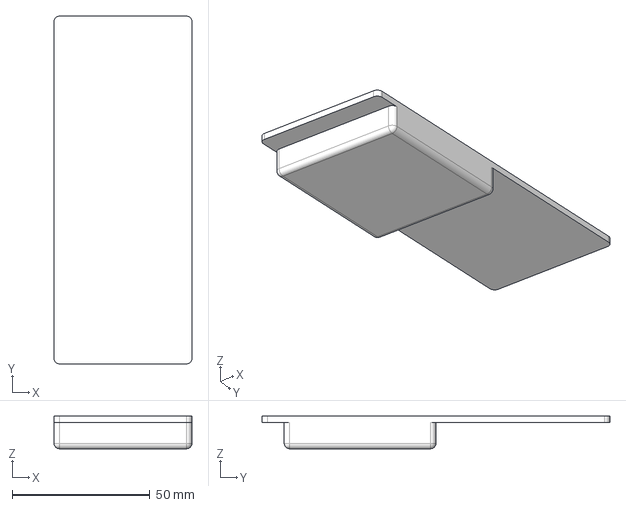
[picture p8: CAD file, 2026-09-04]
hardware/enclosure/step/Battery Holder.step
50.0 x 126.0 x 11.8 mm

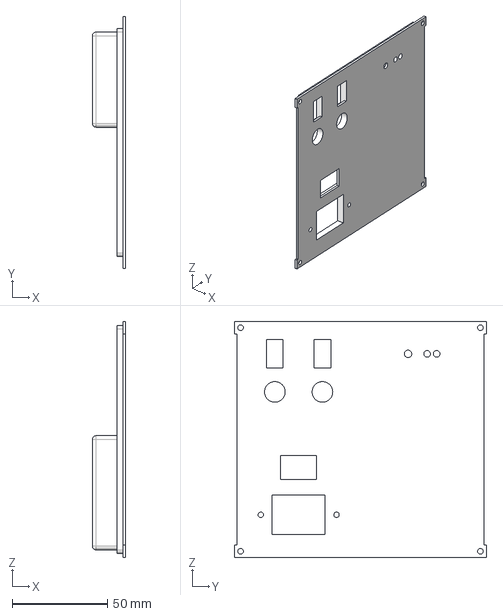
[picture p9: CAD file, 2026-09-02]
hardware/enclosure/step/Side 2.step
17.5 x 132.5 x 124.0 mm

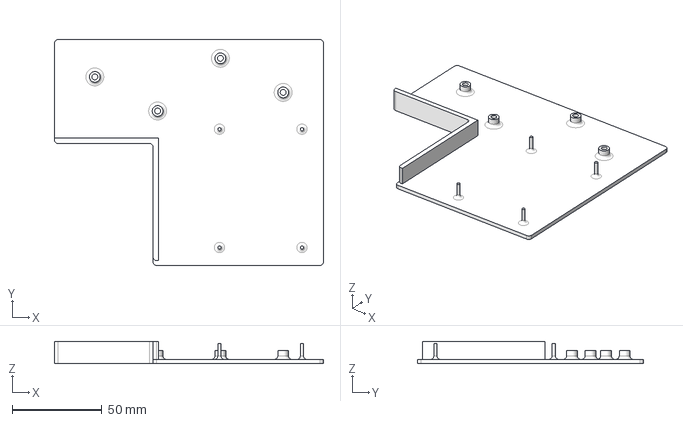
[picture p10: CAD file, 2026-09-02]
hardware/enclosure/step/Level 2.step
150.0 x 126.0 x 12.3 mm

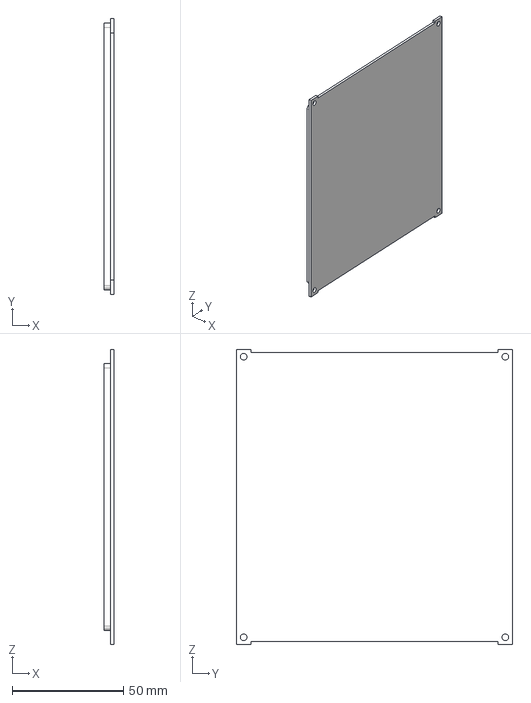
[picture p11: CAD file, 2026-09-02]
hardware/enclosure/step/Side 1.step
4.50 x 124.0 x 132.5 mm

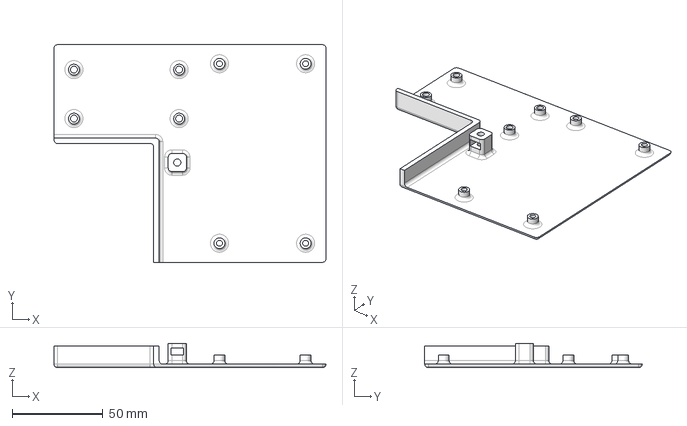
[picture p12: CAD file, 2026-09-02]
hardware/enclosure/step/Level 1.step
150.0 x 120.0 x 13.5 mm

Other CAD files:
hardware/enclosure/3mf/Battery Holder.3mf
hardware/enclosure/3mf/Dummy Sky.3mf
hardware/enclosure/3mf/Level 1.3mf
hardware/enclosure/3mf/Level 2.3mf
hardware/enclosure/3mf/Side 1.3mf
hardware/enclosure/3mf/Side 2.3mf

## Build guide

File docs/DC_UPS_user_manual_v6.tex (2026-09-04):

\documentclass[10.5pt,a5paper]{article}

\usepackage{fontspec}
\setmainfont{DejaVu Serif}
\setsansfont{DejaVu Sans}
\setmonofont{DejaVu Sans Mono}
\usepackage[russian]{babel}
\usepackage{geometry}
\geometry{left=13mm,right=13mm,top=14mm,bottom=16mm}
\usepackage{microtype}
\usepackage{array,tabularx,booktabs}
\usepackage{enumitem}
\usepackage{xcolor}
\usepackage{hyperref}
\usepackage{fancyhdr}
\usepackage{titlesec}
\usepackage{tcolorbox}
\usepackage{qrcode}
\usepackage{graphicx}

% Build identity — same file as the passport and label. Fallbacks let this
% .tex compile standalone in a TeX editor without `make`.
\IfFileExists{build_info.tex}{\input{build_info}}{%
  \newcommand{\hwversion}{v2.1}%
  \newcommand{\fwversion}{dev}%
  \newcommand{\builddate}{unknown}%
  \newcommand{\buildcommit}{unknown}%
  \newcommand{\docrev}{unknown}%
}

% Public documentation site (GitHub Pages). Also the URL encoded in the
% QR code on the enclosure label — change in one place and everything follows.
\newcommand{\docsurl}{https://mrzlohex.github.io/dc-ups-2ch/}

\definecolor{accent}{HTML}{1E5B4F}
\definecolor{lightaccent}{HTML}{EAF3F1}
\definecolor{warn}{HTML}{8B1E1E}
\definecolor{lightwarn}{HTML}{F9ECEC}

\hypersetup{
  colorlinks=true,
  linkcolor=black,
  urlcolor=accent,
  pdfauthor={Изготовитель DC-UPS-2CH},
  pdftitle={Краткое руководство по эксплуатации DC-UPS-2CH \fwversion}
}

\setlength{\parindent}{0pt}
\setlength{\parskip}{0.4em}
\renewcommand{\arraystretch}{1.15}
\setlist[itemize]{leftmargin=5.5mm,itemsep=1.5pt,topsep=2pt}
\setlist[enumerate]{leftmargin=6.5mm,itemsep=2pt,topsep=2pt}

\titleformat{\section}{\large\bfseries\color{accent}}{\thesection.}{0.45em}{}
\titleformat{\subsection}{\normalsize\bfseries}{\thesubsection.}{0.45em}{}

\pagestyle{fancy}
\fancyhf{}
\lhead{\sffamily DC-UPS-2CH}
\rhead{\sffamily Руководство}
\cfoot{\sffamily\small \thepage}
\renewcommand{\headrulewidth}{0.35pt}
\setlength{\headheight}{13pt}

\newtcolorbox{infobox}[1][]{colback=lightaccent,colframe=accent,boxrule=0.7pt,arc=1.5mm,left=2mm,right=2mm,top=1.5mm,bottom=1.5mm,#1}
\newtcolorbox{warnbox}[1][]{colback=lightwarn,colframe=warn,boxrule=0.7pt,arc=1.5mm,left=2mm,right=2mm,top=1.5mm,bottom=1.5mm,#1}

\begin{document}

\begin{titlepage}
\centering
\vspace*{10mm}
{\sffamily\bfseries\fontsize{24}{28}\selectfont DC-UPS-2CH\\[2mm]}
{\sffamily\Large Краткое руководство по эксплуатации\\[5mm]}
{\sffamily\small для прошивки \fwversion\ (сборка \buildcommit, \builddate)}

\vspace{9mm}
\begin{infobox}
\centering
Двухканальный источник резервного питания для роутера, ONT и другого совместимого слаботочного оборудования.
\end{infobox}

\vspace{7mm}
\begin{tabularx}{\textwidth}{@{}lX@{}}
\toprule
Модель & DC-UPS-2CH \hwversion \\
Серийный номер & \rule{45mm}{0.4pt} \\
Дата передачи & \rule{45mm}{0.4pt} \\
Выход ROUTER & \rule{18mm}{0.4pt} В / \rule{18mm}{0.4pt} А \\
Выход ONT & \rule{18mm}{0.4pt} В / \rule{18mm}{0.4pt} А \\
\bottomrule
\end{tabularx}

\vfill
\begin{warnbox}
\textbf{Внимание.} Внутри корпуса присутствует сетевое напряжение 230~В. Пользователь не должен вскрывать корпус при подключённой сети или аккумуляторе.
\end{warnbox}
\vfill
{\small Хранить руководство рядом с устройством.}
\end{titlepage}

\section{Что делает устройство}

DC-UPS-2CH автоматически поддерживает питание двух независимых выходов. В обычном режиме устройство питается от сети и поддерживает аккумулятор в заряженном состоянии. При отключении 230~В переход на аккумулятор происходит автоматически, без действий пользователя.

\begin{tabularx}{\textwidth}{@{}p{44mm}X@{}}
\toprule
\textbf{Параметр} & \textbf{Значение} \\
\midrule
Сеть & 230~В AC, 50~Гц \\
Аккумулятор & 12~В, 7~А\,ч, AGM/SLA \\
Поддерживающий заряд & 13,8~В \\
Ограничение зарядного тока & 1,5~А \\
Предупреждение АКБ & 11,5~В \\
Отключение нагрузки (LVD) & 11,0~В \\
Разрешение повторного запуска & 12,5~В \\
\bottomrule
\end{tabularx}

\begin{infobox}[title=Нормальная работа]
При пропадании света ничего переключать не требуется. Выходы продолжают работу от аккумулятора, пока его напряжение не достигнет защитного порога.
\end{infobox}

\section{Ежедневное использование}

\subsection{Включение}
\begin{enumerate}
  \item Убедиться, что подключены нужные выходы.
  \item На корпусе есть отдельные механические выключатели выходов, перевести требуемые каналы во включённое положение.
  \item Подать 230~В.
  \item Дождаться запуска оборудования и Wi-Fi.
\end{enumerate}

В штатной эксплуатации дальнейшее ручное управление не требуется.

\subsection{При отключении электричества}
Устройство автоматически переходит на АКБ. При наличии связи отправляется уведомление ntfy. При снижении АКБ до 11,5~В отправляется предупреждение. При достижении 11,0~В оба управляемых выхода отключаются для защиты батареи.

После защитного отключения ESP32 переходит в аварийный глубокий сон. Она периодически просыпается и проверяет возврат внешнего питания. Когда сеть вернётся, устройство автоматически возобновит штатную работу.

\begin{warnbox}[title=Не путать с режимом хранения]
После аварийного глубокого сна устройство просыпается от возврата сети автоматически. В \textbf{режиме хранения} возврат 230~В устройство не будит.
\end{warnbox}

\section{Кнопка и индикация}

\subsection{Сервисная кнопка}
\begin{tabularx}{\textwidth}{@{}p{35mm}X@{}}
\toprule
\textbf{Действие} & \textbf{Результат} \\
\midrule
1 короткое нажатие & Отправить полный статус в ntfy \\
2 коротких нажатия & Включить \texttt{DC-UPS-Setup} примерно на 15 минут \\
Удержание 10~с & Перейти в режим хранения \\
Нажатие в режиме хранения& Разбудить устройство и выполнить обычный запуск \\
\bottomrule
\end{tabularx}

\subsection{Подтверждение кнопки}
\begin{itemize}
  \item 2 зелёных мигания --- статус успешно отправлен в ntfy;
  \item 3 красных мигания --- статус отправить не удалось;
  \item краткое совместное мигание LED --- запущен setup AP;
  \item 3 красных мигания перед выключением --- принят переход в режим хранения.
\end{itemize}

\subsection{Обычная индикация}
\begin{tabularx}{\textwidth}{@{}p{35mm}X@{}}
\toprule
Зелёный LED & наличие внешнего питания / сети \\
Красный LED & состояние АКБ, предупреждение или аварийный режим \\
\bottomrule
\end{tabularx}

Пока устройство загружается и подключается к Wi-Fi, зелёный LED мигает с частотой около 2~Гц. Когда активна точка настройки, оба LED медленно чередуются (зелёный/красный, по 500~мс).

\section{Режим хранения}

Режим хранения предназначен для перевозки или длительного хранения устройства, когда оба выхода и Wi-Fi должны быть полностью отключены.

\textbf{Чтобы выключить устройство для хранения:}
\begin{enumerate}
  \item Удерживать сервисную кнопку около 10 секунд.
  \item Дождаться трёх красных миганий.
  \item Отпустить кнопку.
  \item Выходы будут отключены, Wi-Fi выключится, ESP32 уйдёт в deep sleep без периодического таймера.
\end{enumerate}

\textbf{Чтобы снова включить устройство:} один раз нажать сервисную кнопку.

\begin{warnbox}[title=Важно]
В режими хранения устройство просыпается \textbf{только от физической кнопки}. Подключение или возврат 230~В само по себе его не включает.
\end{warnbox}

\section{Веб-панель и Wi-Fi}

При подключении к домашней сети панель доступна по адресу:
\begin{center}
\large\texttt{http://dc-ups.local/}
\end{center}

Также можно использовать IP-адрес, присланный через ntfy.

Через панель можно просматривать напряжения, состояние сети и выходов, Wi-Fi, интернет и журнал событий; управлять режимами ROUTER/ONT; выполнять restart каналов; менять Wi-Fi, ntfy и защитные параметры.

\subsection{Если домашний Wi-Fi недоступен}
Дважды быстро нажать сервисную кнопку. Появится точка доступа:

\begin{center}
\texttt{DC-UPS-Setup}
\end{center}

Пароль по умолчанию: \texttt{dc-ups-setup}, если он не был изменён при настройке.

\section{ntfy}

Устройство само отправляет уведомления о важных событиях. Кроме этого, в тот же topic можно отправить одну из команд:

\begin{center}
\texttt{!ups}\qquad \texttt{!ups status}\qquad \texttt{!ups ping}
\end{center}

Команды только запрашивают состояние и \textbf{не управляют питанием выходов}. Ответ включает напряжение АКБ, 24~В, состояние сети, ROUTER/ONT, интернет, uptime, RSSI и IP.

\begin{infobox}
Команды ntfy работают только когда ESP32 включена, подключена к Wi-Fi и имеет доступ в интернет. В аварийном глубоком сне и режиме хранения Wi-Fi выключен.
\end{infobox}

\section{Подключение оборудования}

Перед подключением нового роутера, ONT или другого устройства обязательно проверить:
\begin{itemize}
  \item требуемое выходное напряжение;
  \item полярность разъёма;
  \item допустимый ток соответствующего выхода;
  \item маркировку ROUTER / ONT на корпусе.
\end{itemize}

Для типового цилиндрического DC-разъёма данного экземпляра полярность должна соответствовать маркировке на корпусе. Не подключать оборудование, если напряжение или полярность неизвестны.

\section{Если что-то не работает}

\begin{tabularx}{\textwidth}{@{}p{43mm}X@{}}
\toprule
\textbf{Симптом} & \textbf{Что сделать} \\
\midrule
Нет питания на выходах & Проверить сеть, механические выключатели, состояние АКБ и режимы каналов в панели \\
Нет веб-панели & Попробовать \texttt{dc-ups.local}; затем дважды нажать кнопку и подключиться к setup AP \\
После отключения света выходы выключились & Возможен нормальный LVD при низком АКБ; дождаться возврата сети \\
После подачи 230~В устройство не запускается & Если ранее включён режим хранения  --- нажать сервисную кнопку \\
3 красных мигания после короткого нажатия & Статус в ntfy не отправлен; проверить Wi-Fi/интернет/topic \\
\bottomrule
\end{tabularx}

Если неисправность повторяется, не вскрывать устройство под напряжением и обратиться к изготовителю/сборщику.

\section{Безопасность и обслуживание}

\begin{itemize}
  \item не эксплуатировать устройство с открытым корпусом;
  \item не допускать воды, конденсата и перекрытия вентиляции;
  \item не замыкать клеммы аккумулятора;
  \item не превышать параметры выходов, указанные на наклейке;
  \item аккумулятор является расходным элементом и со временем теряет ёмкость;
  \item при заметном сокращении времени автономной работы аккумулятор следует проверить и при необходимости заменить в соответствии с полной сервисной документацией.
\end{itemize}

\begin{warnbox}
Перед вскрытием корпуса необходимо отключить 230~В и аккумулятор. Внутреннее обслуживание предназначено для подготовленного лица.
\end{warnbox}

\newpage
\section*{Быстрая памятка}

\begin{infobox}
\textbf{Обычная работа:} ничего переключать не нужно.\\
\textbf{Свет пропал:} устройство работает от АКБ автоматически.\\
\textbf{Свет вернулся:} после аварийного сна устройство восстановится автоматически.\\
\textbf{1x кнопка:} статус в ntfy.\\
\textbf{2x кнопка:} setup AP.\\
\textbf{10 с кнопка:} режим хранения.\\
\textbf{Из хранения:} нажать кнопку.\\
\textbf{Панель:} \texttt{http://dc-ups.local/}.\\
\textbf{ntfy:} \texttt{!ups status} или \texttt{!ups ping}.
\end{infobox}

\vspace{6mm}
\begin{center}
\begin{tabular}{@{}c@{\hspace{14mm}}c@{}}
\qrcode[height=28mm]{http://dc-ups.local/} & \qrcode[height=28mm]{\docsurl} \\[1.5mm]
\\
\\
{\small\parbox{40mm}{\centering Локальная веб-панель\\(та же LAN, поддержка mDNS)}} &
{\small\parbox{40mm}{\centering Онлайн-документация\\(полный паспорт, PDF)}} \\
\end{tabular}
\end{center}

\vfill
\begin{tabularx}{\textwidth}{@{}lX@{}}
Контакт изготовителя: & \rule{50mm}{0.4pt} \\
Дата документа: & \builddate \\
Редакция: & Руководство \fwversion\ / \docrev \\
\end{tabularx}

\end{document}

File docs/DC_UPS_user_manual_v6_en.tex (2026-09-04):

\documentclass[10.5pt,a5paper]{article}

\usepackage{fontspec}
\setmainfont{DejaVu Serif}
\setsansfont{DejaVu Sans}
\setmonofont{DejaVu Sans Mono}
\usepackage[english]{babel}
\usepackage{geometry}
\geometry{left=13mm,right=13mm,top=14mm,bottom=16mm}
\usepackage{microtype}
\usepackage{array,tabularx,booktabs}
\usepackage{enumitem}
\usepackage{xcolor}
\usepackage{hyperref}
\usepackage{fancyhdr}
\usepackage{titlesec}
\usepackage{tcolorbox}
\usepackage{qrcode}
\usepackage{graphicx}

% Build identity — same file as the passport and label. Fallbacks let this
% .tex compile standalone in a TeX editor without `make`.
\IfFileExists{build_info.tex}{\input{build_info}}{%
  \newcommand{\hwversion}{v2.1}%
  \newcommand{\fwversion}{dev}%
  \newcommand{\builddate}{unknown}%
  \newcommand{\buildcommit}{unknown}%
  \newcommand{\docrev}{unknown}%
}

% Public documentation site (GitHub Pages). Also the URL encoded in the
% QR code on the enclosure label — change in one place and everything follows.
\newcommand{\docsurl}{https://mrzlohex.github.io/dc-ups-2ch/}

\definecolor{accent}{HTML}{1E5B4F}
\definecolor{lightaccent}{HTML}{EAF3F1}
\definecolor{warn}{HTML}{8B1E1E}
\definecolor{lightwarn}{HTML}{F9ECEC}

\hypersetup{
  colorlinks=true,
  linkcolor=black,
  urlcolor=accent,
  pdfauthor={DC-UPS-2CH manufacturer},
  pdftitle={DC-UPS-2CH quick user manual \fwversion}
}

\setlength{\parindent}{0pt}
\setlength{\parskip}{0.4em}
\renewcommand{\arraystretch}{1.15}
\setlist[itemize]{leftmargin=5.5mm,itemsep=1.5pt,topsep=2pt}
\setlist[enumerate]{leftmargin=6.5mm,itemsep=2pt,topsep=2pt}

\titleformat{\section}{\large\bfseries\color{accent}}{\thesection.}{0.45em}{}
\titleformat{\subsection}{\normalsize\bfseries}{\thesubsection.}{0.45em}{}

\pagestyle{fancy}
\fancyhf{}
\lhead{\sffamily DC-UPS-2CH}
\rhead{\sffamily User manual}
\cfoot{\sffamily\small \thepage}
\renewcommand{\headrulewidth}{0.35pt}
\setlength{\headheight}{13pt}

\newtcolorbox{infobox}[1][]{colback=lightaccent,colframe=accent,boxrule=0.7pt,arc=1.5mm,left=2mm,right=2mm,top=1.5mm,bottom=1.5mm,#1}
\newtcolorbox{warnbox}[1][]{colback=lightwarn,colframe=warn,boxrule=0.7pt,arc=1.5mm,left=2mm,right=2mm,top=1.5mm,bottom=1.5mm,#1}

\begin{document}

\begin{titlepage}
\centering
\vspace*{10mm}
{\sffamily\bfseries\fontsize{24}{28}\selectfont DC-UPS-2CH\\[2mm]}
{\sffamily\Large Quick user manual\\[5mm]}
{\sffamily\small for firmware \fwversion\ (build \buildcommit, \builddate)}

\vspace{9mm}
\begin{infobox}
\centering
Dual-channel backup power supply for router, ONT and other compatible low-current network equipment.
\end{infobox}

\vspace{7mm}
\begin{tabularx}{\textwidth}{@{}lX@{}}
\toprule
Model & DC-UPS-2CH \hwversion \\
Serial number & \rule{45mm}{0.4pt} \\
Date of transfer & \rule{45mm}{0.4pt} \\
Output ROUTER & \rule{18mm}{0.4pt} V / \rule{18mm}{0.4pt} A \\
Output ONT & \rule{18mm}{0.4pt} V / \rule{18mm}{0.4pt} A \\
\bottomrule
\end{tabularx}

\vfill
\begin{warnbox}
\textbf{Warning.} Dangerous 230~V mains voltage is present inside the enclosure. The user must not open the enclosure while the mains or the battery is connected.
\end{warnbox}
\vfill
{\small Keep this manual next to the device.}
\end{titlepage}

\section{What the device does}

DC-UPS-2CH automatically maintains power on two independent outputs. Under normal conditions the device is powered from the mains and keeps the battery in a charged state. When 230~V mains is lost the switch-over to the battery happens automatically, with no user action required.

\begin{tabularx}{\textwidth}{@{}p{44mm}X@{}}
\toprule
\textbf{Parameter} & \textbf{Value} \\
\midrule
Mains input & 230~V AC, 50~Hz \\
Battery & 12~V, 7~Ah, AGM/SLA \\
Float-charge voltage & 13.8~V \\
Charge current limit & 1.5~A \\
Battery early warning & 11.5~V \\
Load disconnect (LVD) & 11.0~V \\
Load re-enable threshold & 12.5~V \\
\bottomrule
\end{tabularx}

\begin{infobox}[title=Normal operation]
Nothing needs to be switched over during a mains outage. The outputs keep running on the battery until its voltage reaches the protection threshold.
\end{infobox}

\section{Daily use}

\subsection{Turning on}
\begin{enumerate}
  \item Confirm the required outputs are connected.
  \item If the enclosure has separate mechanical output switches, set the required channels to the ON position.
  \item Apply 230~V mains.
  \item Wait for the connected equipment and Wi-Fi to come up.
\end{enumerate}

Under normal operation no further manual control is required.

\subsection{During a mains outage}
The device automatically switches to battery. If a network path is available, an ntfy notification is sent. At battery voltage 11.5~V an early-warning notification is sent. At 11.0~V both managed outputs are shut off to protect the battery.

After protective shut-off the ESP32 enters emergency deep sleep. It wakes periodically and checks whether the mains has returned. When it does, the device automatically resumes normal operation.

\begin{warnbox}[title=Do not confuse with Shelf Sleep]
After emergency deep sleep the device wakes automatically once the mains returns. In \textbf{Shelf Sleep} the return of 230~V does \textbf{not} wake the device.
\end{warnbox}

\section{Button and indication}

\subsection{Service button}
\begin{tabularx}{\textwidth}{@{}p{40mm}X@{}}
\toprule
\textbf{Gesture} & \textbf{Result} \\
\midrule
1 short press & Send full status message to ntfy \\
2 short presses & Open \texttt{DC-UPS-Setup} access point for about 15 minutes \\
Hold for 10~s & Enter Shelf Sleep \\
Any press while in Shelf Sleep & Wake the device and perform a normal start-up \\
\bottomrule
\end{tabularx}

\subsection{Button acknowledgement}
\begin{itemize}
  \item 2 green blinks --- status successfully sent to ntfy;
  \item 3 red blinks --- status could not be sent;
  \item short simultaneous flash of both LEDs --- setup AP has been opened;
  \item 3 red blinks before shutdown --- Shelf Sleep has been accepted.
\end{itemize}

\subsection{Normal indication}
\begin{tabularx}{\textwidth}{@{}p{35mm}X@{}}
\toprule
Green LED & external power / mains present \\
Red LED & battery state, warning or emergency mode \\
\bottomrule
\end{tabularx}

While the device is booting and joining Wi-Fi, the green LED blinks at about 2~Hz. When the setup access point is active, both LEDs alternate slowly (green/red, 500~ms each side).

\section{Shelf Sleep}

Shelf Sleep is intended for transport and long-term storage, when both outputs and Wi-Fi must be completely off.

\textbf{To power the device down for storage:}
\begin{enumerate}
  \item Hold the service button for about 10 seconds.
  \item Wait for three red blinks.
  \item Release the button.
  \item Both outputs will switch off, Wi-Fi will go down, the ESP32 will enter deep sleep with no periodic wake-up.
\end{enumerate}

\textbf{To power the device on again:} press the service button once.

\begin{warnbox}[title=Important]
In Shelf Sleep the device wakes \textbf{only from a physical button press}. Connecting or restoring 230~V mains does not wake it.
\end{warnbox}

\section{Web panel and Wi-Fi}

Once connected to the home network, the panel is available at:
\begin{center}
\large\texttt{http://dc-ups.local/}
\end{center}

The IP address delivered through ntfy on every successful Wi-Fi connect can also be used directly.

The panel shows voltages, mains / output / Wi-Fi / internet status and the event log; lets the user manage ROUTER/ONT modes; perform channel restarts; and change Wi-Fi, ntfy and protection settings.

\subsection{If the home Wi-Fi is not available}
Double-press the service button quickly. An access point will appear:

\begin{center}
\texttt{DC-UPS-Setup}
\end{center}

Default password: \texttt{dc-ups-setup}, unless it was changed during commissioning.

\section{ntfy}

The device sends notifications about important events on its own. In addition, one of the following commands may be posted to the same topic:

\begin{center}
\texttt{!ups}\qquad \texttt{!ups status}\qquad \texttt{!ups ping}
\end{center}

The commands only \textbf{query} state and \textbf{do not control the outputs}. The reply includes battery voltage, 24~V rail, mains status, ROUTER/ONT, internet, uptime, RSSI and IP.

\begin{infobox}
ntfy commands only work while the ESP32 is awake, connected to Wi-Fi and has internet access. In emergency deep sleep and in Shelf Sleep the Wi-Fi radio is off.
\end{infobox}

\section{Connecting equipment}

Before connecting a new router, ONT or other device, always verify:
\begin{itemize}
  \item required output voltage;
  \item barrel plug polarity;
  \item permissible current of the corresponding output;
  \item the ROUTER / ONT labelling on the enclosure.
\end{itemize}

For the standard cylindrical DC connector of this unit, polarity must match the marking on the enclosure. Do not connect equipment when the required voltage or polarity is unknown.

\section{Troubleshooting}

\begin{tabularx}{\textwidth}{@{}p{43mm}X@{}}
\toprule
\textbf{Symptom} & \textbf{What to do} \\
\midrule
No power on the outputs & Check mains, mechanical switches, battery voltage and the per-channel mode in the panel \\
Web panel not reachable & Try \texttt{dc-ups.local}; if it fails, double-press the button and connect to the setup AP \\
Outputs shut off after a mains outage & Normal LVD on low battery; wait for the mains to return \\
Device did not start after mains was restored & Shelf Sleep may be active --- press the service button \\
3 red blinks after a short press & Status was not sent to ntfy; check Wi-Fi / internet / topic \\
\bottomrule
\end{tabularx}

If the fault repeats, do not open the device while it is energised and contact the manufacturer or system integrator.

\section{Safety and maintenance}

\begin{itemize}
  \item do not operate the device with the enclosure open;
  \item do not allow water, condensation or airflow obstruction;
  \item do not short-circuit the battery terminals;
  \item do not exceed the output ratings printed on the label;
  \item the battery is a consumable part and loses capacity over time;
  \item if the autonomous runtime shortens noticeably, the battery should be checked and, if necessary, replaced according to the full service documentation.
\end{itemize}

\begin{warnbox}
Before opening the enclosure disconnect 230~V mains and the battery. Internal servicing is intended for trained personnel.
\end{warnbox}

\newpage
\section*{Quick reference}

\begin{infobox}
\textbf{Normal operation:} nothing to switch.\\
\textbf{Mains lost:} device works from the battery automatically.\\
\textbf{Mains returned:} device recovers from emergency deep sleep automatically.\\
\textbf{1x button:} status to ntfy.\\
\textbf{2x button:} setup AP.\\
\textbf{Hold 10~s:} Shelf Sleep.\\
\textbf{Wake from storage:} press the button.\\
\textbf{Panel:} \texttt{http://dc-ups.local/}.\\
\textbf{ntfy:} \texttt{!ups status} or \texttt{!ups ping}.
\end{infobox}

\vspace{6mm}
\begin{center}
\begin{tabular}{@{}c@{\hspace{14mm}}c@{}}
\qrcode[height=28mm]{http://dc-ups.local/} & \qrcode[height=28mm]{\docsurl} \\[1.5mm]
\\
\\
{\small\parbox{40mm}{\centering Local web panel\\(same LAN, mDNS)}} &
{\small\parbox{40mm}{\centering Online documentation\\(full passport, PDF)}} \\
\end{tabular}
\end{center}

\vfill
\begin{tabularx}{\textwidth}{@{}lX@{}}
Manufacturer contact: & \rule{50mm}{0.4pt} \\
Document date: & \builddate \\
Revision: & User manual \fwversion\ / \docrev \\
\end{tabularx}

\end{document}

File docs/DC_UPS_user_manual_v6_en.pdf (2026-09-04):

# DC-UPS-2CH

## Quick user manual

for firmware 2026.09.02-v6 (build 190fc6b, 2026-09-04)

Dual-channel backup power supply for router, ONT and other compatible low-current network equipment.

Model | DC-UPS-2CH v2.1
Serial number
Date of transfer
Output ROUTER | V / | A
Output ONT | V / | A

Warning. Dangerous 230 V mains voltage is present inside the enclosure. The user must not open the enclosure while the mains or the battery is connected.

Keep this manual next to the device.

DC-UPS-2CH | User manual

### 1. What the device does

DC-UPS-2CH automatically maintains power on two independent outputs. Under normal conditions the device is powered from the mains and keeps the battery in a charged state. When 230 V mains is lost the switch-over to the battery happens automatically, with no user action required.

Parameter | Value
Mains input | 230 V AC, 50 Hz
Battery | 12 V, 7 Ah, AGM/SLA
Float-charge voltage | 13.8 V
Charge current limit | 1.5 A
Battery early warning | 11.5 V
Load disconnect (LVD) | 11.0 V
Load re-enable thresh- old | 12.5 V

Normal operation

Nothing needs to be switched over during a mains outage. The outputs keep running on the battery until its voltage reaches the protection threshold.

### 2. Daily use

### 2.1. Turning on

1. Confirm the required outputs are connected.
2. If the enclosure has separate mechanical output switches, set the required channels to the ON position.
3. Apply 230 V mains.
4. Wait for the connected equipment and Wi-Fi to come up.

Under normal operation no further manual control is required.

### 2.2. During a mains outage

The device automatically switches to battery. If a network path is available, an ntfy notification is sent. At battery voltage 11.5 V an early-warning notification is sent. At 11.0 V both managed outputs are shut off to protect the battery.
After protective shut-off the ESP32 enters emergency deep sleep. It wakes periodically and checks whether the mains has returned. When it does, the device automatically resumes normal operation.

Do not confuse with Shelf Sleep

After emergency deep sleep the device wakes automatically once the mains returns. In Shelf Sleep the return of 230 V does not wake the device.

### 3. Button and indication

### 3.1. Service button

Gesture | Result
1 short press | Send full status message to ntfy
2 short presses | Open DC-UPS-Setup access point for about 15 minutes
Hold for 10 s | Enter Shelf Sleep
Any press while in Shelf Sleep | Wake the device and perform a normal start- up

### 3.2. Button acknowledgement

- 2 green blinks — status successfully sent to ntfy;
- 3 red blinks — status could not be sent;
- short simultaneous flash of both LEDs — setup AP has been opened;
- 3 red blinks before shutdown — Shelf Sleep has been accepted.

### 3.3. Normal indication

Green LED | external power / mains present
Red LED | battery state, warning or emergency mode

While the device is booting and joining Wi-Fi, the green LED blinks at about 2 Hz. When the setup access point is active, both LEDs alternate slowly (green/red, 500 ms each side).

### 4. Shelf Sleep

Shelf Sleep is intended for transport and long-term storage, when both outputs and Wi-Fi must be completely off.
To power the device down for storage:
1. Hold the service button for about 10 seconds.
2. Wait for three red blinks.
3. Release the button.
4. Both outputs will switch off, Wi-Fi will go down, the ESP32 will enter deep sleep with no periodic wake-up.

To power the device on again: press the service button once.

Important

In Shelf Sleep the device wakes only from a physical button press. Connecting or restoring 230 V mains does not wake it.

### 5. Web panel and Wi-Fi

Once connected to the home network, the panel is available at:

### http://dc-ups.local/

The IP address delivered through ntfy on every successful Wi-Fi connect can also be used directly.
The panel shows voltages, mains / output / Wi-Fi / internet status and the event log; lets the user manage ROUTER/ONT modes; perform channel restarts; and change Wi-Fi, ntfy and protection settings.

### 5.1. If the home Wi-Fi is not available

Double-press the service button quickly. An access point will appear:

DC-UPS-Setup

Default password: dc-ups-setup, unless it was changed during commissioning.

### 6. ntfy

The device sends notifications about important events on its own. In addition, one of the following commands may be posted to the same topic:

!ups | !ups status | !ups ping

The commands only query state and do not control the outputs. The reply includes battery voltage, 24 V rail, mains status, ROUTER/ONT, internet, uptime, RSSI and IP.

ntfy commands only work while the ESP32 is awake, connected
to Wi-Fi and has internet access. In emergency deep sleep and in Shelf Sleep the Wi-Fi radio is off.

### 7. Connecting equipment

Before connecting a new router, ONT or other device, always verify:

- required output voltage;
- barrel plug polarity;
- permissible current of the corresponding output;
- the ROUTER / ONT labelling on the enclosure.

For the standard cylindrical DC connector of this unit, polarity must match the marking on the enclosure. Do not connect equipment when the required voltage or polarity is unknown.

### 8. Troubleshooting

Symptom | What to do
No power on the outputs | Check mains, mechanical switches, bat- tery voltage and the per-channel mode in the panel
Web panel not reach- able | Try dc-ups.local; if it fails, double-press the button and connect to the setup AP
Outputs shut off after a mains outage | Normal LVD on low battery; wait for the mains to return
Device did not start af- ter mains was restored | Shelf Sleep may be active — press the ser- vice button
3 red blinks after a short press | Status was not sent to ntfy; check Wi-Fi / internet / topic

If the fault repeats, do not open the device while it is energised and contact the manufacturer or system integrator.

### 9. Safety and maintenance

- do not operate the device with the enclosure open;
- do not allow water, condensation or airflow obstruction;
- do not short-circuit the battery terminals;
- do not exceed the output ratings printed on the label;
- the battery is a consumable part and loses capacity over time;
- if the autonomous runtime shortens noticeably, the battery should be checked and, if necessary, replaced according to the full service documentation.

Before opening the enclosure disconnect 230 V mains and the battery. Internal servicing is intended for trained personnel.

### Quick reference

Normal operation: nothing to switch.
Mains lost: device works from the battery automatically. Mains returned: device recovers from emergency deep sleep automatically.
1x button: status to ntfy.
2x button: setup AP.
Hold 10 s: Shelf Sleep.
Wake from storage: press the button. Panel: http://dc-ups.local/. ntfy: !ups status or !ups ping.

Local web panel
(same LAN, mDNS)

Online documentation
(full passport, PDF)

Manufacturer contact:
Document date: | 2026-09-04
Revision: | User manual 2026.09.02-v6 / 190fc6b

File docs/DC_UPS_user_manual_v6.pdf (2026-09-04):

# DC-UPS-2CH

## Краткое руководство по эксплуатации

для прошивки 2026.09.02-v6 (сборка 190fc6b, 2026-09-04)

Двухканальный источник резервного питания для роутера, ONT и другого совместимого слаботочного оборудования.

Модель | DC-UPS-2CH v2.1
Серийный номер
Дата передачи
Выход ROUTER | В / | А
Выход ONT | В / | А

Внимание. Внутри корпуса присутствует сетевое напряжение 230 В. Пользователь не должен вскрывать корпус при подключённой сети или аккумуляторе.

Хранить руководство рядом с устройством.

DC-UPS-2CH | Руководство

### 1. Что делает устройство

DC-UPS-2CH автоматически поддерживает питание двух независимых выходов. В обычном режиме устройство питается от сети и поддерживает аккумулятор в заряженном состоянии. При отключении 230 В переход на аккумулятор происходит автоматически, без действий пользователя.

Параметр | Значение
Сеть | 230 В AC, 50 Гц
Аккумулятор | 12 В, 7 А ч, AGM/SLA
Поддерживающий заряд | 13,8 В
Ограничение зарядно- го тока | 1,5 А
Предупреждение АКБ | 11,5 В
Отключение нагрузки (LVD) | 11,0 В
Разрешение повторно- го запуска | 12,5 В

Нормальная работа

При пропадании света ничего переключать не требуется. Выходы продолжают работу от аккумулятора, пока его напряжение не достигнет защитного порога.

### 2. Ежедневное использование

### 2.1. Включение

1. Убедиться, что подключены нужные выходы.
2. На корпусе есть отдельные механические выключатели выходов, перевести требуемые каналы во включённое положение.
3. Подать 230 В.
4. Дождаться запуска оборудования и Wi-Fi.

В штатной эксплуатации дальнейшее ручное управление не требуется.

### 2.2. При отключении электричества

Устройство автоматически переходит на АКБ. При наличии связи отправляется уведомление ntfy. При снижении АКБ до 11,5 В отправляется предупреждение. При достижении 11,0 В оба управляемых выхода отключаются для защиты батареи.
После защитного отключения ESP32 переходит в аварийный глубокий сон. Она периодически просыпается и проверяет возврат внешнего питания. Когда сеть вернётся, устройство автоматически возобновит штатную работу.

Не путать с режимом хранения

После аварийного глубокого сна устройство просыпается от возврата сети автоматически. В режиме хранения возврат 230 В устройство не будит.

### 3. Кнопка и индикация

### 3.1. Сервисная кнопка

Действие | Результат
1 короткое нажа- тие | Отправить полный статус в ntfy
2 коротких нажа- тия | Включить DC-UPS-Setup примерно на 15 ми- нут
Удержание 10 с | Перейти в режим хранения
Нажатие в режи- ме хранения | Разбудить устройство и выполнить обычный запуск

### 3.2. Подтверждение кнопки

- 2 зелёных мигания — статус успешно отправлен в ntfy;
- 3 красных мигания — статус отправить не удалось;

- краткое совместное мигание LED — запущен setup AP;
- 3 красных мигания перед выключением — принят переход в режим хранения.

### 3.3. Обычная индикация

Зелёный LED | наличие внешнего питания / сети
Красный LED | состояние АКБ, предупреждение или ава- рийный режим

Пока устройство загружается и подключается к Wi-Fi, зелёный LED мигает с частотой около 2 Гц. Когда активна точка настройки, оба LED медленно чередуются (зелёный/красный, по 500 мс).

### 4. Режим хранения

Режим хранения предназначен для перевозки или длительного хранения устройства, когда оба выхода и Wi-Fi должны быть полностью отключены.
Чтобы выключить устройство для хранения:
1. Удерживать сервисную кнопку около 10 секунд.
2. Дождаться трёх красных миганий.
3. Отпустить кнопку.
4. Выходы будут отключены, Wi-Fi выключится, ESP32 уйдёт в deep sleep без периодического таймера.

Чтобы снова включить устройство: один раз нажать сервисную кнопку.

Важно

В режими хранения устройство просыпается только от физической кнопки. Подключение или возврат 230 В само по себе его не включает.

### 5. Веб-панель и Wi-Fi

При подключении к домашней сети панель доступна по адресу:

### http://dc-ups.local/

Также можно использовать IP-адрес, присланный через ntfy. Через панель можно просматривать напряжения, состояние сети и выходов, Wi-Fi, интернет и журнал событий; управлять режимами ROUTER/ONT; выполнять restart каналов; менять Wi-Fi, ntfy и защитные параметры.

### 5.1. Если домашний Wi-Fi недоступен

Дважды быстро нажать сервисную кнопку. Появится точка доступа:

DC-UPS-Setup

Пароль по умолчанию: dc-ups-setup, если он не был изменён при настройке.

### 6. ntfy

Устройство само отправляет уведомления о важных событиях. Кроме этого, в тот же topic можно отправить одну из команд:

!ups | !ups status | !ups ping

Команды только запрашивают состояние и не управляют питанием выходов. Ответ включает напряжение АКБ, 24 В, состояние сети, ROUTER/ONT, интернет, uptime, RSSI и IP.

Команды ntfy работают только когда ESP32 включена, подключена к Wi-Fi и имеет доступ в интернет. В аварийном глубоком сне и режиме хранения Wi-Fi выключен.

### 7. Подключение оборудования

Перед подключением нового роутера, ONT или другого устройства обязательно проверить:

- требуемое выходное напряжение;
- полярность разъёма;
- допустимый ток соответствующего выхода;
- маркировку ROUTER / ONT на корпусе.

Для типового цилиндрического DC-разъёма данного экземпляра полярность должна соответствовать маркировке на корпусе. Не подключать оборудование, если напряжение или полярность неизвестны.

### 8. Если что-то не работает

Симптом | Что сделать

Нет питания на выходах

Проверить сеть, механические выключатели, состояние АКБ и режимы каналов в панели
Нет веб-панели | Попробовать dc-ups.local; затем два-
жды нажать кнопку и подключиться к setup AP
После отключения
света выходы выключились

Возможен нормальный LVD при низком АКБ; дождаться возврата сети

После подачи 230 В
устройство не запускается

Если ранее включён режим хранения — нажать сервисную кнопку

3 красных мигания после короткого нажатия

Статус в ntfy не отправлен; проверить Wi-Fi/интернет/topic

Если неисправность повторяется, не вскрывать устройство под напряжением и обратиться к изготовителю/сборщику.

### 9. Безопасность и обслуживание

- не эксплуатировать устройство с открытым корпусом;
- не допускать воды, конденсата и перекрытия вентиляции;
- не замыкать клеммы аккумулятора;
- не превышать параметры выходов, указанные на наклейке;
- аккумулятор является расходным элементом и со временем теряет ёмкость;
- при заметном сокращении времени автономной работы аккумулятор следует проверить и при необходимости заменить в соответствии с полной сервисной документацией.

Перед вскрытием корпуса необходимо отключить 230 В и аккумулятор. Внутреннее обслуживание предназначено для подготовленного лица.

### Быстрая памятка

Обычная работа: ничего переключать не нужно.
Свет пропал: устройство работает от АКБ автоматически. Свет вернулся: после аварийного сна устройство восстановится автоматически.
1x кнопка: статус в ntfy.
2x кнопка: setup AP.
10 с кнопка: режим хранения. Из хранения: нажать кнопку. Панель: http://dc-ups.local/. ntfy: !ups status или !ups ping.

Локальная веб-панель
(та же LAN, поддержка
mDNS)

Онлайн-документация
(полный паспорт, PDF)

Контакт изготовителя:
Дата документа: | 2026-09-04
Редакция: | Руководство 2026.09.02-v6 / 190fc6b

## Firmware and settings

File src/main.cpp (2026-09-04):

// SPDX-License-Identifier: GPL-3.0-or-later
//
// DC-UPS-2CH — ESP32 backup power controller for network gear.
//   - two independent DC outputs (ROUTER, ONT) via high-side P-MOSFETs;
//   - battery / 24 V sensing on ADC1 (100k/10k dividers, x11);
//   - web panel, mDNS, ntfy (outgoing + read-only inbound commands);
//   - emergency deep sleep (timer wake) + Shelf Sleep (button-only wake);
//   - staged auto-recovery: probe -> power-cycle -> optional ESP reboot.
//
// No external Arduino libraries: everything ships in the ESP32 core.
// Wiring, GPIO map, BOM: hardware/README.md.
// Full passport: docs/DC_UPS_documentation_v6.tex (RU) / _en.tex (EN).

#include <Arduino.h>
#include "esp_task_wdt.h"
#include "esp_sleep.h"

#include "ups_common.h"
#include "config_store.h"
#include "event_log.h"
#include "hardware.h"
#include "power.h"
#include "wifi_mgr.h"
#include "ntfy.h"
#include "recovery.h"
#include "sleep_modes.h"
#include "web_ui.h"
#include "boot_flow.h"

void setup()
{
    Serial.begin(115200);

    esp_sleep_wakeup_cause_t wakeCause = esp_sleep_get_wakeup_cause();

    initHardware();

    esp_task_wdt_init(WDT_TIMEOUT_SEC, true);
    esp_task_wdt_add(NULL);

    loadConfig();

    // Restore persistent event-log tail BEFORE the boot line so pre-reboot
    // entries appear first, in order, and the fresh "BOOT ..." line follows.
    loadPersistentEventLog();

    // First measurement before WiFi — also decides whether to go straight
    // back into emergency sleep on a low battery.
    lastVbatt = readVoltage(PIN_VBATT, DIV_VBATT, cfg.calVbatt);
    lastVgrid = readVoltage(PIN_VGRID, DIV_VGRID, cfg.calVgrid);

    battState       = getBattState(lastVbatt);
    gridPresent     = lastVgrid > cfg.gridOn;
    gridCandidate   = gridPresent;
    gridChangeSince = millis();

    handleWakeCause(wakeCause);

    bool wokeFromEmergencySleep =
        (wakeCause == ESP_SLEEP_WAKEUP_TIMER && rtcEmergencySleep);

    BootInputs bin = {
        wokeFromEmergencySleep,
        gridPresent, lastVbatt,
        cfg.battCutoff, cfg.battRestore, cfg.battSleep,
        cfg.deepSleepEnabled
    };

    switch (decideBootAction(bin))
    {
        case BOOT_EMERGENCY_SLEEP_AGAIN:
        {
            rtcSleepWakeCount++;
            Serial.printf("Emergency wake #%lu: Vbat=%.2f V24=%.2f -> sleep again\n",
                          (unsigned long)rtcSleepWakeCount, lastVbatt, lastVgrid);
            emergencySleepTimerOnly();  // [[noreturn]]
        }
        break;

        case BOOT_EMERGENCY_SLEEP_COLD:
        {
            rtcEmergencySleep = true;
            rtcShelfSleep     = false;
            rtcSleepWakeCount = 0;
            Serial.printf("Cold boot with low battery %.2f V -> emergency sleep\n",
                          lastVbatt);
            emergencySleepTimerOnly();  // [[noreturn]]
        }
        break;

        case BOOT_NORMAL:
            if (wokeFromEmergencySleep)
            {
                uint32_t sleptChecks = rtcSleepWakeCount;
                rtcEmergencySleep    = false;
                rtcSleepWakeCount    = 0;

                nextWifiConnectReason =
                    "ИБП проснулся после аварийного сна. Проверок во сне: " +
                    String(sleptChecks) + ".";
            }
            break;
    }

    logEvent("BOOT FW " FW_FULL_ID +
             String(" | АКБ ") + String(lastVbatt, 2) +
             " В | 24В "        + String(lastVgrid, 2) +
             " В | сеть "       + (gridPresent ? "есть" : "нет"));

    if (!gridPresent)
    {
        outageStartedAt = millis();
        outageCount     = 1;
    }

    // KEY POINT: the ESP controls power to the router whose WiFi it must join.
    // Turn the loads on first, wait for the router to boot, then try WiFi.
    if (canPowerLoadsOnBoot(gridPresent, lastVbatt, cfg.battCutoff))
    {
        setRouter(true);
        setOnt(true);
    }
    else
    {
        setBothLoads(false);
        if (shouldArmLvdAtBoot(gridPresent, lastVbatt, cfg.battCutoff))
        {
            lvdTripped    = true;
            sleepLowSince = millis();
        }
    }

    if (cfg.ssid == "")
    {
        wifiStatusText = "SSID не задан";
        startPortal();
    }
    else if (!routerOn)
    {
        wifiStatusText = "роутер отключён: АКБ ниже отсечки";
        startPortal();
    }
    else
    {
        Serial.printf("Waiting %lu ms for ROUTER/ONT boot...\n",
                      (unsigned long)ROUTER_BOOT_MS);
        waitWithWatchdog(ROUTER_BOOT_MS);

        if (connectSTABlocking(WIFI_CONNECT_TIMEOUT_MS))
        {
            wifiWasConnected = true;
            handleWifiConnected();
        }
        else
        {
            wifiWasConnected = false;
            wifiStatusText   = "WiFi не найден; портал активен";
            logEvent("WiFi не найден -> запускаю setup portal");
            startPortal();
        }
    }

    // WiFi is now initialised (STA via connectSTABlocking, or AP+STA via
    // startPortal). Safe to open the TCP socket for the WebServer.
    beginWeb();

    updateLeds();
}

void loop()
{
    esp_task_wdt_reset();

    protectTick();
    powerCycleTick();
    buttonTick();
    deepSleepTick();
    rebootTick();
    updateLeds();

    // The WebServer runs on both home WiFi and the setup AP.
    server.handleClient();

    if (portalActive)
        dns.processNextRequest();

    wifiRetryTick();
    wifiTick();
    portalMaintenanceTick();
    networkRecoveryTick();
    ntfyTick();
    ntfyCommandTick();
}

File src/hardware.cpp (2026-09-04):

// SPDX-License-Identifier: GPL-3.0-or-later
#include "hardware.h"

#include "ups_common.h"
#include "event_log.h"
#include "power.h"
#include "ntfy.h"
#include "wifi_mgr.h"
#include "sleep_modes.h"

#include "esp_task_wdt.h"
#include "driver/rtc_io.h"

bool    buttonIgnoreUntilRelease = false;
LedMode ledMode                  = LED_MODE_RUN;

// Button state machine — internal only.
static bool          s_raw            = HIGH;
static bool          s_stable         = HIGH;
static bool          s_longHandled    = false;
static uint8_t       s_clickCount     = 0;
static unsigned long s_rawChangedAt   = 0;
static unsigned long s_pressedAt      = 0;
static unsigned long s_firstClickAt   = 0;

void initHardware()
{
    // After EXT0 wake the pin is still in RTC mode — return it to plain GPIO.
    rtc_gpio_deinit((gpio_num_t)PIN_BUTTON);

    pinMode(PIN_LED_GRID,    OUTPUT);
    pinMode(PIN_LED_BATT,    OUTPUT);
    pinMode(PIN_LOAD_ROUTER, OUTPUT);
    pinMode(PIN_LOAD_ONT,    OUTPUT);
    pinMode(PIN_BUTTON,      INPUT_PULLUP);

    // Both power switches must be guaranteed off at boot.
    digitalWrite(PIN_LOAD_ROUTER, LOW);
    digitalWrite(PIN_LOAD_ONT,    LOW);
    routerOn = false;
    ontOn    = false;

    s_raw    = digitalRead(PIN_BUTTON);
    s_stable = s_raw;

    // LED self-test.
    digitalWrite(PIN_LED_GRID, HIGH);
    digitalWrite(PIN_LED_BATT, HIGH);
    delay(400);
    digitalWrite(PIN_LED_GRID, LOW);
    digitalWrite(PIN_LED_BATT, LOW);

    analogReadResolution(12);
    analogSetPinAttenuation(PIN_VBATT, ADC_11db);
    analogSetPinAttenuation(PIN_VGRID, ADC_11db);
}

void handleWakeCause(esp_sleep_wakeup_cause_t cause)
{
    if (cause == ESP_SLEEP_WAKEUP_EXT0 && rtcShelfSleep)
    {
        rtcShelfSleep        = false;
        rtcEmergencySleep    = false;
        rtcSleepWakeCount    = 0;
        buttonIgnoreUntilRelease = true;
        nextWifiConnectReason = "DC-UPS включён кнопкой из режима хранения.";
        Serial.println("Wake from SHELF SLEEP by GPIO14 button");
    }
}

void updateLeds()
{
    switch (ledMode)
    {
        case LED_MODE_BOOT_WIFI:
        {
            // Green blinks at ~2 Hz (250 ms half-period); red stays off.
            // Distinguishes "ESP alive, joining WiFi" from "ESP silent".
            bool on = ((millis() / 250) & 1) != 0;
            digitalWrite(PIN_LED_GRID, on ? HIGH : LOW);
            digitalWrite(PIN_LED_BATT, LOW);
            return;
        }

        case LED_MODE_PORTAL:
        {
            // Slow alternating green/red (500 ms each side): user can tell
            // "setup portal is active" from across the room and it's clearly
            // not the normal RUN indication.
            bool phase = ((millis() / 500) & 1) != 0;
            digitalWrite(PIN_LED_GRID,  phase ? HIGH : LOW);
            digitalWrite(PIN_LED_BATT, !phase ? HIGH : LOW);
            return;
        }

        case LED_MODE_RUN:
        default:
            break;
    }

    // RUN mode: steady green iff grid present.
    digitalWrite(PIN_LED_GRID, gridPresent ? HIGH : LOW);

    bool red;
    if (battState == BATT_CRIT || (!gridPresent && !anyLoadOn()))
        red = true;
    else if (gridPresent && battState == BATT_OK)
        red = false;
    else
    {
        const int period = (battState == BATT_WARN) ? 250 : 1000;
        red = ((millis() / period) % 2) != 0;
    }

    digitalWrite(PIN_LED_BATT, red ? HIGH : LOW);
}

static void handleButtonShort()
{
    logEvent("Кнопка: короткое -> запрос статуса ntfy");
    bool ok = sendNtfy(buildStatusMessage("Статус DC-UPS по кнопке"));

    // Feedback: 2 green blinks = sent, 3 red blinks = WiFi/ntfy down.
    uint8_t count = ok ? 2 : 3;
    int     pin   = ok ? PIN_LED_GRID : PIN_LED_BATT;
    for (uint8_t i = 0; i < count; ++i)
    {
        digitalWrite(pin, HIGH);
        delay(90);
        digitalWrite(pin, LOW);
        delay(90);
        esp_task_wdt_reset();
    }
    updateLeds();
}

static void handleButtonDouble()
{
    startManualPortalFromButton();
}
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

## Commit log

2026-09-04 feat(led): mode state machine (boot / run / portal), feat(time): NTP sync + wall-clock event log, feat(log): persist last 24 entries across reboots, refactor(boot): extract pure decisions to boot_flo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
    [hardware.cpp, main.cpp]
2026-09-04 en doubled docs
    [Battery Holder.3mf, Battery Holder.step, DC_UPS.3mf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]
